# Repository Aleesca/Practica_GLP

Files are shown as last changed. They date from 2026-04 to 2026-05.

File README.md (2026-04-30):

# Proyecto de Instalacion de GLP

Base documental y de coordinacion para el calculo y diseno de una instalacion de almacenamiento y distribucion de GLP del grupo `G1-1`.

## Quick Start

1. Revisa el alcance en `Proyecto/Alcance.md`.
2. Revisa los datos de partida en `Proyecto/Datos.md`.
3. Usa `Proyecto/Planificacion/esquema_memoria.md` y `Proyecto/Especificaciones/metodologia.md` como contrato de trabajo.
4. Desarrolla las notas tecnicas en `Proyecto/Anotaciones/` y la salida final en `Proyecto/Especificaciones/`.
5. Consulta la documentacion tecnica de apoyo en `.agents/skills/doc_tecnica_glp/`.
6. Consolida editorialmente en `Practica_GLPs_LaTeX/` solo cuando el contenido Markdown ya este cerrado.

## Estructura operativa

- `00_Info_proporcionada/`: datos de partida, enunciado y modelo base del proyecto.
- `01_Planos/`: planos de trabajo y archivo CAD base.
- `Proyecto/Planificacion/`: gobierno documental, trazabilidad y planes de trabajo.
- `Proyecto/Especificaciones/`: salida tecnica primaria en Markdown modular.
- `Proyecto/Anotaciones/`: notas tecnicas, criterios y soporte intermedio.
- `.agents/skills/`: skills operativas canonicas del proyecto.
- `Proyecto/skills/`: espejo temporal de skills para apoyo documental.
- `Practica_GLPs_LaTeX/`: consolidacion editorial posterior; no es la fuente de verdad tecnica.
- `ZZ_Normativa/`: normativa de referencia y documentos reglamentarios.

## Decisiones de arquitectura

- El flujo activo se gobierna por `Proyecto/Alcance.md`, `Proyecto/Datos.md`, `Proyecto/Planificacion/esquema_memoria.md` y `Proyecto/Especificaciones/metodologia.md`.
- `Proyecto/Especificaciones/` es la salida primaria del sistema.
- `Practica_GLPs_LaTeX/` se mantiene como capa de consolidacion posterior.
- `.agents/skills/` es la ubicacion operativa de skills.
- `Proyecto/skills/` se conserva como espejo temporal y no debe gobernar el sistema activo.

## Documentacion clave

- `Proyecto/Alcance.md`
- `Proyecto/Datos.md`
- `Proyecto/Planificacion/esquema_memoria.md`
- `Proyecto/Especificaciones/metodologia.md`
- `Proyecto/Planificacion/matriz_fuentes.md`
- `Proyecto/Planificacion/mapa_citas.md`

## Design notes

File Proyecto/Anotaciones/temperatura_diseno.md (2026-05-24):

# Temperatura exterior de calculo

Esta nota fija el criterio para determinar la temperatura exterior de diseño del proyecto, basándose en referencias técnicas oficiales y el ajuste local.

## Referencia Técnica
Se adopta el criterio de la **Guía técnica: Condiciones climáticas exteriores de proyecto** (IDAE), utilizando el **percentil 99,6%** ajustado.

- **Fuente:** [IDAE - Guía técnica condiciones climáticas](https://www.idae.es/uploads/documentos/documentos_12_Guia_tecnica_condiciones_climaticas_exteriores_de_proyecto_e4e5b769.pdf)
- **Ubicación:** León (Virgen del Camino).
- **Temperatura de cálculo (99,6%):** **-5 ºC**.

## Uso en el proyecto
Esta temperatura es fundamental para la comprobación de la [vaporización natural](vaporizacion_natural.md) de los depósitos seleccionados en [seleccion_deposito.md](seleccion_deposito.md).

---
**Véase también:**
- [Vaporización natural](vaporizacion_natural.md)
- [Vaporización forzada](vaporizacion_forzada.md)
- [Selección del depósito](seleccion_deposito.md)
- [Potencia del armario de calefacción](potencia_armario_calefaccion.md)
- [Memoria: Hipótesis y datos de partida](../Especificaciones/datos-partida.md)
- [Memoria: Vaporización natural vs. vaporización forzada](../Especificaciones/vaporizacion.md)
- [Memoria: Conclusiones y limitaciones del proyecto](../Especificaciones/conclusiones-limitaciones.md)

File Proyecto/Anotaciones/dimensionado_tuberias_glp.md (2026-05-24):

# Dimensionado de tuberias GLP

El presente documento desarrolla el dimensionado de la red de distribucion de GLP en fase gas, incluyendo criterios de calculo, seleccion de materiales, formulacion hidraulica, optimizacion de diametros y resultados finales por tramo.

## Criterios tecnicos adoptados

El dimensionado de la red de distribucion de GLP se realiza para un regimen de media presion, con presion inicial relativa de `1.70 bar`. La perdida de carga admisible se limita al `5.0%` de dicha presion inicial, lo que fija una presion minima de servicio en el extremo mas desfavorable de `1.615 bar relativos`.

La red se calcula para propano en fase gas. Se adopta densidad corregida Renouard `dc = 1.16` y poder calorifico superior de `13.95 kWh/kg` para transformar la potencia termica instalada en caudal masico. El paso a caudal volumetrico se realiza con densidad de propano gas `1.882 kg/m3`.

La red se proyecta para GLP en fase gas y trazado exterior aereo. Se adopta tuberia metalica de cobre duro estirado sin soldadura conforme a EN 1057, con espesor minimo de 1 mm, por su compatibilidad con instalaciones receptoras de GLP y por permitir ejecucion vista protegida. El polietileno se descarta para estos tramos al tratarse de conduccion aerea expuesta; el acero al carbono se considera alternativa tecnica posible si se justifica proteccion frente a corrosion y autorizacion/criterio especifico aplicable a media presion.

### Criterio de velocidad: limite aereo y limite de proyecto

Para una canalizacion aerea de GLP en fase gas se toma como referencia general el limite maximo de `20 m/s`, asociado a redes generales de distribucion y acometidas aereas. No obstante, el presente proyecto no corresponde a una red general de distribucion de GLP canalizado para distintos abonados, sino a una instalacion receptora alimentada desde almacenamiento propio que suministra a consumidores finales de un unico usuario industrial. De acuerdo con la clasificacion tecnica de instalaciones receptoras, cuando existe un unico usuario la IRG se considera instalacion individual; para instalacion comun o individual el limite de velocidad aplicable es `10 m/s`. Por ello se adopta `10 m/s` como limite de proyecto y `8-10 m/s` como rango operativo preferente. El valor `20 m/s` queda documentado solo como limite maximo de referencia para conducciones aereas generales, pero no gobierna la seleccion de diametros de esta instalacion receptora industrial.

La fuente de calculo empleada establece tres limites de velocidad por tipo de conduccion: `30 m/s` para red general enterrada, `20 m/s` para red general y acometidas aereas, y `10 m/s` para instalacion comun en edificios e instalacion individual. La misma documentacion define que la red de distribucion no existe en GLP a granel y que, si la instalacion receptora suministra a un unico usuario, se considera instalacion individual. En consecuencia, cada tramo se comprueba frente a `v <= 10.0 m/s` como criterio aplicable de proyecto; el valor `v <= 20.0 m/s` se conserva solo como contraste de limite aereo general. La seleccion final prioriza el intervalo `8-10 m/s` cuando el catalogo y la presion disponible lo permiten.

Desde el punto de vista de optimizacion, el diametro seleccionado no se determina unicamente por velocidad. Para cada tramo se comprueba simultaneamente la condicion de aplicacion de Renouard `Q/D < 150`, la presion minima final, la velocidad practica y el catalogo comercial disponible. En tramos terminales de pequeno caudal puede aparecer velocidad baja cuando ya se ha alcanzado el diametro comercial minimo. En ramales de mayor longitud se evalua ademas el equilibrio entre aumentar ligeramente el tramo comun aguas arriba y reducir el diametro del ramal final, usando la masa lineal del tubo como estimador tecnico del coste.

## Material y catalogo de calculo

Material adoptado: **Cobre duro estirado sin soldadura EN 1057, espesor minimo 1 mm, instalacion aerea protegida**.

Se selecciona cobre duro estirado sin soldadura como material metalico apto para la red exterior en fase gas de GLP. Esta solución evita recurrir a PE en tramos aereos y simplifica la proteccion frente a corrosion respecto al acero al carbono. El PE se descarta por ser canalizacion aerea exterior. La alternativa de acero al carbono queda tecnicamente posible solo con proteccion pasiva y autorizacion o documentacion especifica. La seleccion queda supeditada a que el material mantenga presion maxima admisible suficiente frente a la presion de servicio y a las condiciones de montaje exterior.

El catalogo utilizado incorpora diametro interior, espesor, diametro exterior y masa lineal estimada a partir de la seccion metalica y densidad del cobre `8960 kg/m3`. Esta masa lineal se emplea solo como criterio comparativo interno para seleccionar alternativas equivalentes desde el punto de vista hidraulico.

Las dimensiones comerciales y masas lineales empleadas se han contrastado con tablas de tuberia de cobre conforme a EN 1057 para aplicaciones de agua/gas y con tablas tecnicas de instalaciones de GLP. Como referencias externas de material se consideran: [EN 1057:2006+A1:2010 - seamless copper tubes for water and gas](https://standards.iteh.ai/catalog/standards/cen/472e132f-b218-4e1e-9158-a3974034b500/en-1057-2006a1-2010), [Manual de instalaciones de GLP - Cepsa](https://15f8034cdff6595cbfa1-1dd67c28d3aade9d3442ee99310d18bd.ssl.cf3.rackcdn.com/04422d24271abec52042f58a558069bf/1_09_glp_cepsa.pdf), [COPTECH - tubos de cobre duro R290 EN 1057](https://www.copper.rs/hard.html) y [ALSIMET - tabla de tubo sanitario EN 1057](https://alsimet.es/en/copper/copper-tubes/sanitary-copper). Estas referencias se usan para justificar el tipo de tubo, la nomenclatura `diametro exterior x espesor`, el uso de cobre duro y la estimacion de masa lineal; el catalogo definitivo debera validarse con el proveedor antes de presupuesto.

| material | designacion | D_int_mm | espesor_mm | D_ext_mm | area_metal_mm2 | masa_lineal_kg_m |
| --- | --- | --- | --- | --- | --- | --- |
| cobre_duro_en1057 | 15x1 | 13.000 | 1.000 | 15.000 | 43.982 | 0.394 |
| cobre_duro_en1057 | 18x1.5 | 15.000 | 1.500 | 18.000 | 77.754 | 0.697 |
| cobre_duro_en1057 | 18x1 | 16.000 | 1.000 | 18.000 | 53.407 | 0.479 |
| cobre_duro_en1057 | 20x1.5 | 17.000 | 1.500 | 20.000 | 87.179 | 0.781 |
| cobre_duro_en1057 | 22x1 | 20.000 | 1.000 | 22.000 | 65.973 | 0.591 |
| cobre_duro_en1057 | 28x1 | 26.000 | 1.000 | 28.000 | 84.823 | 0.760 |
| cobre_duro_en1057 | 35x1.5 | 32.000 | 1.500 | 35.000 | 157.865 | 1.414 |
| cobre_duro_en1057 | 42x1.5 | 39.000 | 1.500 | 42.000 | 190.852 | 1.710 |
| cobre_duro_en1057 | 54x2 | 50.000 | 2.000 | 54.000 | 326.726 | 2.927 |
| cobre_duro_en1057 | 64x2 | 60.000 | 2.000 | 64.000 | 389.557 | 3.490 |
| cobre_duro_en1057 | 76.1x2 | 72.100 | 2.000 | 76.100 | 465.584 | 4.172 |
| cobre_duro_en1057 | 88.9x2 | 84.900 | 2.000 | 88.900 | 546.009 | 4.892 |
| cobre_duro_en1057 | 108x2.5 | 103.000 | 2.500 | 108.000 | 828.595 | 7.424 |

## Formulacion empleada

La potencia de cada consumidor se transforma a caudal masico y volumetrico mediante:

```text
Q_kg/h = P_kW / PCS_propano
Q_m3/h = Q_kg/h / rho_propano_gas
```

Para el consumidor `C6`, de `1000 kW`, resulta:

```text
Q_kg/h = 1000 / 13.95 = 71.68 kg/h
Q_m3/h = 71.68 / 1.882 = 38.09 m3/h
```

La longitud de calculo se obtiene sumando a la longitud geometrica la longitud equivalente de accesorios:

```text
Lc(D) = Lreal + sum(n_i * K_i * D_mm / 1000)
```

Para el tramo `E-C6`, con `Lreal = 14.46 m`, diametro interior `26 mm` y accesorios equivalentes `te_desviada + valvula_corte + reduccion`, se obtiene `Lc = 16.540 m`.

La perdida de carga en media presion se calcula con Renouard:

```text
PA_abs^2 - PB_abs^2 = 51.5 * dc * Lc * Q^1.82 / D^4.82
```

Para `E-C6`, con `PA_rel = 1.641 bar`, `Q = 38.090 m3/h`, `D = 26 mm` y `Lc = 16.540 m`, la presion final calculada es `PB_rel = 1.620 bar`, con perdida de carga `0.021 bar`.

La velocidad del gas se comprueba mediante:

```text
v = 378.04 * Q / (P_abs * D^2)
```

En el mismo tramo `E-C6`, el resultado es `v = 8.089 m/s`, dentro del rango operativo de `8-10 m/s`.

## Consumidores y caudales

| nodo | nombre | potencia_kw | q_kg_h | q_m3_h |
| --- | --- | --- | --- | --- |
| C1 | Horno secado 1 | 60 | 4.301 | 2.285 |
| C2 | Horno secado 2 | 60 | 4.301 | 2.285 |
| C3 | Caldera vapor | 500 | 35.842 | 19.045 |
| C4 | Caldera agua caliente | 300 | 21.505 | 11.427 |
| C5 | Horno fusion | 700 | 50.179 | 26.663 |
| C6 | Horno decapado | 1000 | 71.685 | 38.090 |

## Topologia y caudales por tramo

Los caudales aguas arriba se obtienen por suma de los consumidores descendentes, sin simultaneidad adicional. La fila inicial de derivaciones verticales de deposito se trata como cuatro subtramos equivalentes de `1,90 m` y se resume agrupada en la tabla posterior.

| designacion | tipo_tramo | nodo_ini | nodo_fin | longitud_m | q_m3_h | q_kg_h |
| --- | --- | --- | --- | --- | --- | --- |
| D1-D4 | derivacion_deposito | D1 | D4 | 1.900 | 24.949 | 46.953 |
| D2-D4 | derivacion_deposito | D2 | D4 | 1.900 | 24.949 | 46.953 |
| D3-D4 | derivacion_deposito | D3 | D4 | 1.900 | 24.949 | 46.953 |
| D4 vertical | derivacion_deposito | D4_dep | D4 | 1.900 | 24.949 | 46.953 |
| D4-A | red_principal | D4 | A | 15.120 | 99.795 | 187.814 |
| A-C1 | red_principal | A | C1 | 1.810 | 2.285 | 4.301 |
| A-B | red_principal | A | B | 4.970 | 97.509 | 183.513 |
| B-C2 | red_principal | B | C2 | 21.790 | 2.285 | 4.301 |
| B-C | red_principal | B | C | 17.320 | 95.224 | 179.211 |
| C-C3 | red_principal | C | C3 | 1.750 | 19.045 | 35.842 |
| C-D | red_principal | C | D | 10.770 | 76.179 | 143.369 |
| D-C4 | red_principal | D | C4 | 1.680 | 11.427 | 21.505 |
| D-E | red_principal | D | E | 13.060 | 64.752 | 121.864 |
| E-C5 | red_principal | E | C5 | 1.690 | 26.663 | 50.179 |
| E-C6 | red_principal | E | C6 | 14.460 | 38.090 | 71.685 |

## Accesorios considerados

El inventario de accesorios se introduce como longitud equivalente proporcional al diametro. Se consideran codos por cambios de direccion, tes en derivaciones, valvulas de corte por consumidor y por salida de deposito, y reducciones cuando el ramal deriva hacia un diametro inferior.

En el tramo `B-C2` se conserva la longitud real `21,79 m`, ya que corresponde a la suma de `0,53 m` a nivel de suelo, `8,00 m` de subida, `5,26 m` de tramo horizontal aereo y `8,00 m` de bajada. La revision no altera dicha longitud geometrica, pero si incorpora cuatro codos de 90 grados asociados a los cambios de direccion suelo-subida, subida-horizontal, horizontal-bajada y conexion final al consumidor. El desnivel no se corrige mediante termino hidrostatico porque el ramal sube y baja hasta una cota final equivalente y la comprobacion se realiza para GLP en fase gas.

| designacion | accesorio | cantidad | coef_leq_D | criterio |
| --- | --- | --- | --- | --- |
| D1-D4 | codo_90 | 1 | 30 | visible/hipotesis conservadora segun esquema_instalacion.pdf |
| D1-D4 | valvula_corte | 1 | 10 | visible/hipotesis conservadora segun esquema_instalacion.pdf |
| D2-D4 | codo_90 | 1 | 30 | visible/hipotesis conservadora segun esquema_instalacion.pdf |
| D2-D4 | valvula_corte | 1 | 10 | visible/hipotesis conservadora segun esquema_instalacion.pdf |
| D3-D4 | codo_90 | 1 | 30 | visible/hipotesis conservadora segun esquema_instalacion.pdf |
| D3-D4 | valvula_corte | 1 | 10 | visible/hipotesis conservadora segun esquema_instalacion.pdf |
| D4 vertical | codo_90 | 1 | 30 | visible/hipotesis conservadora segun esquema_instalacion.pdf |
| D4 vertical | valvula_corte | 1 | 10 | visible/hipotesis conservadora segun esquema_instalacion.pdf |
| D4-A | codo_90 | 1 | 30 | visible/hipotesis conservadora segun esquema_instalacion.pdf |
| D4-A | valvula_corte | 1 | 10 | visible/hipotesis conservadora segun esquema_instalacion.pdf |
| D4-A | te_linea | 1 | 20 | visible/hipotesis conservadora segun esquema_instalacion.pdf |
| A-C1 | te_desviada | 1 | 60 | visible/hipotesis conservadora segun esquema_instalacion.pdf |
| A-C1 | valvula_corte | 1 | 10 | visible/hipotesis conservadora segun esquema_instalacion.pdf |
| A-C1 | reduccion | 1 | 10 | visible/hipotesis conservadora segun esquema_instalacion.pdf |
| A-B | codo_90 | 1 | 30 | visible/hipotesis conservadora segun esquema_instalacion.pdf |
| A-B | te_linea | 1 | 20 | visible/hipotesis conservadora segun esquema_instalacion.pdf |
| B-C2 | te_desviada | 1 | 60 | visible/hipotesis conservadora segun esquema_instalacion.pdf |
| B-C2 | valvula_corte | 1 | 10 | visible/hipotesis conservadora segun esquema_instalacion.pdf |
| B-C2 | reduccion | 1 | 10 | visible/hipotesis conservadora segun esquema_instalacion.pdf |
| B-C2 | codo_90 | 4 | 30 | visible/hipotesis conservadora segun esquema_instalacion.pdf |
| B-C | codo_90 | 1 | 30 | visible/hipotesis conservadora segun esquema_instalacion.pdf |
| B-C | te_linea | 1 | 20 | visible/hipotesis conservadora segun esquema_instalacion.pdf |
| C-C3 | te_desviada | 1 | 60 | visible/hipotesis conservadora segun esquema_instalacion.pdf |
| C-C3 | valvula_corte | 1 | 10 | visible/hipotesis conservadora segun esquema_instalacion.pdf |
| C-C3 | reduccion | 1 | 10 | visible/hipotesis conservadora segun esquema_instalacion.pdf |
| C-D | codo_90 | 1 | 30 | visible/hipotesis conservadora segun esquema_instalacion.pdf |
| C-D | te_linea | 1 | 20 | visible/hipotesis conservadora segun esquema_instalacion.pdf |
| D-C4 | te_desviada | 1 | 60 | visible/hipotesis conservadora segun esquema_instalacion.pdf |
| D-C4 | valvula_corte | 1 | 10 | visible/hipotesis conservadora segun esquema_instalacion.pdf |
| D-C4 | reduccion | 1 | 10 | visible/hipotesis conservadora segun esquema_instalacion.pdf |
| D-E | codo_90 | 1 | 30 | visible/hipotesis conservadora segun esquema_instalacion.pdf |
| D-E | te_linea | 1 | 20 | visible/hipotesis conservadora segun esquema_instalacion.pdf |
| E-C5 | te_desviada | 1 | 60 | visible/hipotesis conservadora segun esquema_instalacion.pdf |
| E-C5 | valvula_corte | 1 | 10 | visible/hipotesis conservadora segun esquema_instalacion.pdf |
| E-C5 | reduccion | 1 | 10 | visible/hipotesis conservadora segun esquema_instalacion.pdf |
| E-C6 | te_desviada | 1 | 60 | visible/hipotesis conservadora segun esquema_instalacion.pdf |
| E-C6 | valvula_corte | 1 | 10 | visible/hipotesis conservadora segun esquema_instalacion.pdf |
| E-C6 | reduccion | 1 | 10 | visible/hipotesis conservadora segun esquema_instalacion.pdf |

### Sensibilidad del tramo B-C2

| subtramo | descripcion | longitud_m | tipo |
| --- | --- | --- | --- |
| B-C2.1 | tramo inicial a nivel de suelo | 0.530 | horizontal_suelo |
| B-C2.2 | subida vertical hasta tramo aereo | 8.000 | vertical_subida |
| B-C2.3 | tramo horizontal aereo | 5.260 | horizontal_aereo |
| B-C2.4 | bajada vertical hasta consumidor C2 | 8.000 | vertical_bajada |

La comparacion siguiente muestra el efecto de incorporar los codos del trazado vertical-aereo. El diametro se mantiene en `15x1`, por ser el minimo del catalogo adoptado y porque la presion final sigue por encima del minimo admisible.

| escenario | designacion_tubo | D_int_mm | Lc_m | P_ini_rel_bar | P_fin_rel_bar | delta_p_bar | velocidad_ms | incremento_Lc_m | incremento_delta_p_bar |
| --- | --- | --- | --- | --- | --- | --- | --- | --- | --- |
| anterior: sin codos vertical-aereo adicionales | 15x1 | 13.000 | 22.830 | 1.675 | 1.670 | 0.005 | 1.905 | 0.000 | 0.000 |
| revisado: con 4 codos 90 por subida/bajada | 15x1 | 13.000 | 24.390 | 1.675 | 1.670 | 0.005 | 1.905 | 1.560 | 0.000 |

Como condicion constructiva, el tramo aereo debe resolverse con soportes que no carguen sobre uniones, separacion respecto a paramentos, proteccion anticorrosiva, identificacion de fase gas y previsiones de dilatacion si la longitud expuesta queda sometida a variaciones termicas relevantes.

## Derivaciones verticales de deposito

| designacion | unidades | longitud_m_por_unidad | q_m3_h_por_unidad | designacion_tubo | D_int_mm | Lc_m_por_unidad | P_fin_rel_bar_min | velocidad_ms_max | estado |
| --- | --- | --- | --- | --- | --- | --- | --- | --- | --- |
| D1/D2/D3/D4 verticales | 4 | 1.900 | 24.949 | 20x1.5 | 17.000 | 2.580 | 1.688 | 12.080 | Conforme |

### Verificacion y Justificacion de Cumplimiento de la Normativa UNE 60250

De acuerdo con la norma **UNE 60250** ("Instalaciones de almacenamiento de GLP en depositos fijos para su consumo en instalaciones receptoras"), la zona de almacenamiento (los depositos y sus derivaciones inmediatas hasta el colector comun) esta sujeta a requisitos especificos de resistencia mecanica y seguridad pasiva frente a incendios:

1. **Requisitos de Tuberia de Cobre en la Zona del Deposito (UNE 60250):**
   * **Espesor minimo:** Las conducciones de cobre situadas en la zona de almacenamiento deben tener un espesor de pared de al menos **1.5 mm** (`espesor_mm >= 1.5`).
   * **Diametro exterior maximo:** El diametro nominal maximo para estas derivaciones es de **DN 20** (diametro exterior de **20 mm**).
   * **Inconformidad del diseño original:** El diseño inicial contemplaba tuberias de cobre de `22x1` para las derivaciones verticales de los depositos (`D1-D4`, `D2-D4`, `D3-D4`, `D4 vertical`). Este diseño resultaba doblemente no conforme:
     * El espesor de pared de `1.0 mm` no alcanzaba el minimo de `1.5 mm`.
     * El diametro exterior de `22.0 mm` superaba el limite reglamentario de `20.0 mm`.
   * **Seleccion del diametro conforme:** Tras filtrar el catalogo comercial por los requisitos de la UNE 60250, se selecciono el diametro **20x1.5** (diametro exterior de 20 mm, espesor de 1.5 mm, diametro interior de 17 mm).

2. **Criterios de Velocidad y Perdida de Carga:**
   * **Velocidad del fluido:** Con el diametro adoptado de `20x1.5`, la velocidad maxima alcanzada en las derivaciones verticales es de **12.08 m/s** para el caudal punta por deposito. Aunque este valor supera el limite practico de `10.0 m/s` establecido para la red receptora interior (UNE 60670), es plenamente conforme bajo la UNE 60250, que permite un limite absoluto de velocidad de **20 m/s** en conducciones aereas de almacenamiento y distribucion exterior.
   * **Perdida de carga:** La caida de presion en cada ramal es de solo **0.012 bar**, manteniendo la presion final en el nodo colector en **1.688 bar relativos**, asegurando que no se penalice el funcionamiento hidraulico del sistema.

3. **Requisitos de las Uniones y Accesorios (UNE-EN 1254-1 / UNE 60250):**
   * **Soldadura capilar fuerte:** Para garantizar la estanqueidad y evitar fallos por fatiga termica o exposicion directa al fuego, las uniones de las tuberias en el area de almacenamiento deben ser mediante **soldadura fuerte con metal de aportación que tenga un punto de fusion superior a 450 °C**. Queda estrictamente prohibido el uso de soldadura blanda en esta zona.
   * **Impacto en accesorios de reduccion:** La sustitucion del ramal a `20x1.5` en lugar de `22x1` modifica las uniones al colector comun de `42x1.5`. Se requiere la instalacion de **5 reducciones de cobre de 42 mm a 20 mm** (en las conexiones de los 4 depositos y en el tramo de derivacion `C-C3` que tambien optimizo a `20x1.5` por balance de velocidad), sustituyendo las reducciones de `42x22` originalmente previstas.

## Optimizacion hidraulica y economica del subarbol E

El tramo `E-C6` es un ramal largo con caudal relevante. El dimensionado secuencial inicial mantenia `D-E` en `35x1.5` y obligaba a seleccionar `E-C6` en `35x1.5` para cumplir presion, lo que dejaba una velocidad baja en el ramal final. Para evitar esta solucion local, se evalua de forma combinada el conjunto `D-E`, `E-C5` y `E-C6`.

La seleccion se realiza sobre combinaciones comerciales que cumplen `Q/D`, presion minima y `v <= 10.0 m/s`, ordenadas por masa equivalente total de cobre. La alternativa adoptada incrementa `D-E` a `42x1.5`, reduciendo su perdida de carga a `0.007 bar` y elevando la presion disponible en el nodo `E` hasta `1.641 bar`. Con esa presion disponible, `E-C6` puede reducirse a `28x1` y queda con velocidad `8.089 m/s`, dentro del rango objetivo.

| D-E_tubo | E-C5_tubo | E-C6_tubo | D-E_velocidad_ms | E-C5_velocidad_ms | E-C6_velocidad_ms | D-E_P_fin_rel_bar | E-C5_P_fin_rel_bar | E-C6_P_fin_rel_bar | masa_total_kg |
| --- | --- | --- | --- | --- | --- | --- | --- | --- | --- |
| 42x1.5 | 22x1 | 28x1 | 6.062 | 9.520 | 8.089 | 1.641 | 1.634 | 1.620 | 34.322 |
| 42x1.5 | 28x1 | 28x1 | 6.062 | 5.622 | 8.089 | 1.641 | 1.639 | 1.620 | 34.607 |
| 42x1.5 | 35x1.5 | 28x1 | 6.062 | 3.709 | 8.089 | 1.641 | 1.640 | 1.620 | 35.713 |
| 42x1.5 | 42x1.5 | 28x1 | 6.062 | 2.497 | 8.089 | 1.641 | 1.641 | 1.620 | 36.213 |
| 42x1.5 | 54x2 | 28x1 | 6.062 | 1.519 | 8.089 | 1.641 | 1.641 | 1.620 | 38.270 |

La velocidad de `D-E` queda en `6.062 m/s`, por debajo del rango preferente, pero se considera justificada porque el tramo comun conserva margen de presion y permite reducir material en el ramal largo `E-C6`. El tramo `E-C5` mantiene `22x1` con velocidad `9.520 m/s`.

## Justificacion de velocidades bajas

Determinados tramos presentan velocidades inferiores al rango preferente `8-10 m/s`. Estos casos no se clasifican automaticamente como sobredimensionado, ya que el criterio principal es garantizar simultaneamente presion minima, condicion `Q/D < 150`, diametro comercial disponible y velocidad maxima admisible. La velocidad baja se acepta solo cuando existe una causa tecnica identificable.

- `A-C1` y `B-C2`: ambos alimentan consumidores de `60 kW`, con caudal `2.285 m3/h`. El diametro seleccionado es `15x1`, con diametro interior `13 mm`, que es el minimo del catalogo adoptado. En `B-C2`, la revision del trazado vertical-aereo aumenta la longitud de calculo por los cuatro codos adicionales, pero el diametro no cambia y la presion final permanece conforme. La velocidad resultante queda en torno a `1.9 m/s`; reducir el diametro para aproximarse a `8-10 m/s` exigiria introducir un tubo no contemplado en el catalogo de calculo y con menor robustez mecanica. Por tanto, la baja velocidad se justifica por caudal reducido, diametro comercial minimo y margen de presion suficiente aun incorporando los cambios de direccion.

- `C-C3`: alimenta el consumidor de `500 kW`, con caudal `19.045 m3/h`. El tubo `22x1` proporciona `6.752 m/s`, por debajo del rango preferente pero cumpliendo presion y `Q/D`. El diametro inmediatamente inferior elevaria la velocidad, pero penalizaria la perdida de carga y reduciria el margen de presion disponible en un ramal conectado a la red principal. Se mantiene `22x1` como equilibrio entre margen hidraulico y dimension comercial.

- `C-D`: transporta el caudal remanente hacia los consumidores `C4`, `C5` y `C6`. La seleccion `42x1.5` da `7.113 m/s`, ligeramente inferior al objetivo, pero mantiene margen de presion para el subarbol final y evita trasladar una perdida excesiva a los ramales aguas abajo. La velocidad baja se considera admisible por equilibrio hidraulico de conjunto.

- `D-E`: tras la optimizacion combinada del subarbol `E`, se adopta `42x1.5`, con `6.062 m/s`. Esta reduccion de velocidad en el tramo comun permite elevar la presion en el nodo `E` y reducir `E-C6` a `28x1`, donde la velocidad pasa a `8.089 m/s`. El criterio no minimiza la velocidad de cada tramo de forma aislada, sino la solucion conjunta de presion, perdida de carga y masa equivalente de tubo.

## Resultados de dimensionado

| designacion | tipo_tramo | longitud_m | q_m3_h | designacion_tubo | D_int_mm | Lc_m | Q_D | P_ini_rel_bar | P_fin_rel_bar | delta_p_bar | velocidad_ms | criterio_seleccion | estado |
| --- | --- | --- | --- | --- | --- | --- | --- | --- | --- | --- | --- | --- | --- |
| D1-D4 | derivacion_deposito | 1.900 | 24.949 | 20x1.5 | 17.000 | 2.580 | 1.468 | 1.700 | 1.688 | 0.012 | 12.080 | no hay candidato <=10 m/s; se mantiene bajo limite aereo absoluto de 20 m/s | Conforme - velocidad alta admisible por limite aereo general |
| D2-D4 | derivacion_deposito | 1.900 | 24.949 | 20x1.5 | 17.000 | 2.580 | 1.468 | 1.700 | 1.688 | 0.012 | 12.080 | no hay candidato <=10 m/s; se mantiene bajo limite aereo absoluto de 20 m/s | Conforme - velocidad alta admisible por limite aereo general |
| D3-D4 | derivacion_deposito | 1.900 | 24.949 | 20x1.5 | 17.000 | 2.580 | 1.468 | 1.700 | 1.688 | 0.012 | 12.080 | no hay candidato <=10 m/s; se mantiene bajo limite aereo absoluto de 20 m/s | Conforme - velocidad alta admisible por limite aereo general |
| D4 vertical | derivacion_deposito | 1.900 | 24.949 | 20x1.5 | 17.000 | 2.580 | 1.468 | 1.700 | 1.688 | 0.012 | 12.080 | no hay candidato <=10 m/s; se mantiene bajo limite aereo absoluto de 20 m/s | Conforme - velocidad alta admisible por limite aereo general |
| D4-A | red_principal | 15.120 | 99.795 | 42x1.5 | 39.000 | 17.460 | 2.559 | 1.700 | 1.682 | 0.018 | 9.203 | diametro con velocidad dentro de 8-10 m/s mas cercana a 9.5 m/s | Conforme - velocidad objetivo |
| A-C1 | red_principal | 1.810 | 2.285 | 15x1 | 13.000 | 2.850 | 0.176 | 1.682 | 1.681 | 0.001 | 1.897 | diametro mas cercano al rango objetivo sin superar el limite practico de 10 m/s | Conforme - velocidad baja justificada |
| A-B | red_principal | 4.970 | 97.509 | 42x1.5 | 39.000 | 6.920 | 2.500 | 1.682 | 1.675 | 0.007 | 9.015 | diametro con velocidad dentro de 8-10 m/s mas cercana a 9.5 m/s | Conforme - velocidad objetivo |
| B-C2 | red_principal | 21.790 | 2.285 | 15x1 | 13.000 | 24.390 | 0.176 | 1.675 | 1.670 | 0.005 | 1.905 | diametro mas cercano al rango objetivo sin superar el limite practico de 10 m/s | Conforme - velocidad baja justificada |
| B-C | red_principal | 17.320 | 95.224 | 42x1.5 | 39.000 | 19.270 | 2.442 | 1.675 | 1.657 | 0.018 | 8.864 | diametro con velocidad dentro de 8-10 m/s mas cercana a 9.5 m/s | Conforme - velocidad objetivo |
| C-C3 | red_principal | 1.750 | 19.045 | 20x1.5 | 17.000 | 3.110 | 1.120 | 1.657 | 1.648 | 0.009 | 9.361 | diametro con velocidad dentro de 8-10 m/s mas cercana a 9.5 m/s | Conforme - velocidad objetivo |
| C-D | red_principal | 10.770 | 76.179 | 42x1.5 | 39.000 | 12.720 | 1.953 | 1.657 | 1.649 | 0.008 | 7.113 | diametro mas cercano al rango objetivo sin superar el limite practico de 10 m/s | Conforme - velocidad baja justificada |
| D-C4 | red_principal | 1.680 | 11.427 | 15x1 | 13.000 | 2.720 | 0.879 | 1.649 | 1.638 | 0.011 | 9.642 | diametro con velocidad dentro de 8-10 m/s mas cercana a 9.5 m/s | Conforme - velocidad objetivo |
| D-E | red_principal | 13.060 | 64.752 | 42x1.5 | 39.000 | 15.010 | 1.660 | 1.649 | 1.641 | 0.007 | 6.062 | optimizacion economica del subarbol E: aumenta D-E para reducir masa total en E-C6 | Conforme - velocidad baja justificada |
| E-C5 | red_principal | 1.690 | 26.663 | 22x1 | 20.000 | 3.290 | 1.333 | 1.641 | 1.634 | 0.008 | 9.520 | seleccionado por optimizacion economica del subarbol E con presion aguas arriba recalculada | Conforme - velocidad objetivo |
| E-C6 | red_principal | 14.460 | 38.090 | 28x1 | 26.000 | 16.540 | 1.465 | 1.641 | 1.620 | 0.021 | 8.089 | seleccionado por optimizacion economica del subarbol E con presion aguas arriba recalculada | Conforme - velocidad objetivo |

## No conformidades

No se detectan no conformidades.

## Control manual de trazabilidad

Como control independiente se recalcula el tramo `D4-A`:

```text
Lc = 17.460 m
Q/D = 2.559
v = 9.203 m/s
```

El resultado confirma la coherencia entre longitud de calculo, caudal, diametro y velocidad final del tramo principal de alimentacion.

## Conclusion tecnica

Con las hipotesis adoptadas, la red queda dimensionada para un caudal punta simultaneo de `187.81 kg/h`, equivalente a `99.79 m3/h`. Todos los tramos cumplen la condicion de aplicacion `Q/D < 150`, la presion minima relativa de `1.615 bar` y el limite practico de velocidad adoptado. Las velocidades bajas que permanecen en ramales concretos responden al diametro comercial minimo o a una decision de equilibrio hidraulico-economico, y quedan justificadas de forma expresa en la tabla de resultados.

---
**Véase también:**
- [Memoria: Hipótesis y datos de partida](../Especificaciones/datos-partida.md)
- [Caudales de consumidores](caudales_consumidores.md)
- [Trazado de red](trazado_red.md)
- [Valvulería y accesorios](valvuleria_accesorios.md)
- [Criterios normativos](criterios_normativos.md)
- [Recopilación de accesorios y costes](recopilacion_accesorios_costes_glp.md)
- [Pliego de condiciones de equipos](pliego_condiciones_equipos_glp.md)
- [Memoria: Red de distribución y regulación](../Especificaciones/red-distribucion.md)
- [Especificación: Metodología de longitud y cálculo hidráulico](../Especificaciones/metodologia-longitud-calculo.md)
- [Especificación: Capítulo de Cálculos justificados](../Especificaciones/calculos-justificados.md)
- [Especificación: Presupuesto y mediciones](../Especificaciones/presupuesto.md)

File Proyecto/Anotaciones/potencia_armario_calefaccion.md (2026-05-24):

# Potencia del armario de calefaccion

Esta nota documenta el criterio de calculo de la potencia termica minima del armario de calefaccion asociado al sistema de [vaporizacion forzada](vaporizacion_forzada.md).

## 1. Necesidad tecnica del armario

La [vaporizacion natural](vaporizacion_natural.md) de la bateria de depositos no cubre la demanda punta de la instalacion en la condicion critica de diseno. La comprobacion se realiza con:

- Temperatura exterior de calculo: **-5 ºC**, definida en [temperatura_diseno.md](temperatura_diseno.md).
- Nivel minimo operativo: **20%** de llenado.
- Presion de comprobacion: **2 bar**.

En estas condiciones, la demanda punta obtenida a partir de los [caudales de consumidores](caudales_consumidores.md) es **187,81 kg/h**, mientras que la vaporizacion natural total de la bateria seleccionada es **131,30 kg/h**. Por tanto, aparece un deficit de:

$$
Q_{def} = 187,81 - 131,30 = 56,51\ \text{kg/h}
$$

Este deficit hace necesario un aporte termico externo. El armario de calefaccion no se incorpora como mejora opcional, sino como equipo funcional imprescindible para alimentar el circuito cerrado de agua caliente que transfiere calor al serpentín interno del vaporizador.

## 2. Criterio de dimensionado

El sistema adoptado en [seleccion_deposito.md](seleccion_deposito.md) es un deposito **LP46A-22** como modelo especial con vaporizador interno **VIA 150**. El criterio de dimensionado del armario se fija por la potencia minima de caldera requerida por el vaporizador seleccionado, no solo por el deficit instantaneo de vaporizacion natural.

Segun la tabla tecnica utilizada en `calculos/calculos.ipynb`, el **VIA 150** tiene:

- Capacidad de vaporizacion forzada: **150 kg/h**.
- Potencia minima de caldera: **17,5 kW**.

La consulta documental al notebook `GLP` confirma el mismo valor para el **VIA 150** y permite identificar que el armario **VPC30C** incorpora una caldera de **45 kW**.

La capacidad total garantizada con el sistema mixto queda:

$$
Q_{total} = Q_{natural} + Q_{forzada} = 131,30 + 150 = 281,30\ \text{kg/h}
$$

El margen frente a la demanda punta es:

$$
Q_{margen} = 281,30 - 187,81 = 93,49\ \text{kg/h}
$$

## 3. Resultado

La potencia termica minima exigida para el generador del armario de calefaccion asociado al **VIA 150** es:

$$
P_{armario,min} = 17,5\ \text{kW}
$$

El armario seleccionado, identificado en la documentacion del proyecto como **VPC30C**, incorpora una caldera de **45 kW**. La comprobacion de suficiencia queda:

$$
45,0\ \text{kW} \ge 17,5\ \text{kW}
$$

Por tanto, el margen de potencia termica disponible en el armario es:

$$
P_{margen} = 45,0 - 17,5 = 27,5\ \text{kW}
$$

## 4. Conclusion

La instalacion del armario de calefaccion es necesaria porque la vaporizacion natural disponible en las condiciones criticas de diseno no garantiza el caudal requerido por la instalacion. Con el vaporizador interno **VIA 150** y una potencia minima de caldera de **17,5 kW**, el sistema mixto alcanza **281,30 kg/h**, suficiente para cubrir la demanda punta de **187,81 kg/h**. El armario **VPC30C**, con **45 kW**, cubre la potencia minima exigida.

---
**Véase también:**
- [Caudales de consumidores](caudales_consumidores.md)
- [Vaporización natural](vaporizacion_natural.md)
- [Vaporización forzada](vaporizacion_forzada.md)
- [Selección del depósito](seleccion_deposito.md)
- [Temperatura exterior de cálculo](temperatura_diseno.md)
- [Pliego de condiciones de equipos](pliego_condiciones_equipos_glp.md)
- [Memoria: Vaporización natural vs. vaporización forzada](../Especificaciones/vaporizacion.md)
- [Memoria: Características de los equipos auxiliares del almacenamiento](../Especificaciones/equipos-auxiliares.md)
- [Memoria: Instalaciones auxiliares y de seguridad de la estación](../Especificaciones/instalaciones-auxiliares.md)

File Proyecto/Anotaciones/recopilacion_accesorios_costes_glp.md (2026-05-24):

# Recopilación y Coste de Accesorios por Tramo GLP (Refinado Final - Rev A)

## Introducción y Alcance
Este documento presenta la estimación técnico-económica definitiva para la instalación de GLP del Grupo G1-1. Se han consolidado los precios mediante investigación profunda, reflejando la configuración final de la batería de depósitos (125,1 m³) necesaria para cumplir con las distancias de seguridad en la parcela. Se utiliza a **Salvador Escoda** como proveedor consolidado para tubería de cobre.

## Fuentes de Consulta y Enlaces de Compra
- **Tubería y Valvulería de Corte**: [Salvador Escoda - Tarifa PVP Cobre/Gas](https://wrs01.salvadorescoda.com/Tarifas_web/actualizadas/Precios_Escoda_PVP_Cobre.pdf) / [Giacomini R731GA](https://es.giacomini.com/product/R731GA)
- **Reguladores**: [Clesse APS2000 (Catálogo Internacional)](https://clesse.eu/wp-content/uploads/2024/05/International_Catalogue.pdf)
- **Seguridad (Válvulas Alivio/Corte Depósito)**: [RegO Europe - RS 3145 / A 7508](https://www.rego-europe.de/)
- **Depósitos y Vaporización**: [Lapesa - Catálogo GLP 2024](https://www.lapesa.es/sites/default/files/nuevo_cat_glp-es-0121-10.pdf)

## Criterios Normativos Aplicados
| Familia | Norma | Requisito Clave | Estado |
| :--- | :--- | :--- | :--- |
| **Tubería** | UNE-EN 1057 | Cobre duro, espesor mín. 1 mm (aéreo) / 1,5 mm (enterrado). | Verificado |
| **Válvulas de Corte** | UNE-EN 331 | PN 16/25/40, -20ºC, mando amarillo para gas. | Verificado |
| **Válvulas Alivio** | UNE-EN 14129 | Taradas a 20 bar, precintadas y certificadas de origen. | Verificado |
| **Depósitos** | UNE 60250 | Distancias de seguridad críticas; fragmentación de volumen. | Cumplido |

## Partidas de Materiales (Proveedor Único: Salvador Escoda)
| Tramo | Diámetro | Componente | Cantidad | Precio Unit. (€/m o ud) | Total (€) |
| :--- | :--- | :--- | :--- | :--- | :--- |
| D1/2/3/4 | 20x1.5 mm | Tubo Cobre Barra | 7,60 m | 16,40 €/m | 124,64 € |
| D4-A / A-B | 42x1.5 mm | Tubo Cobre Barra | 20,09 m | 42,50 €/m | 853,83 € |
| B-C / C-D | 42x1.5 mm | Tubo Cobre Barra | 28,09 m | 42,50 €/m | 1.193,83 € |
| D-E | 42x1.5 mm | Tubo Cobre Barra | 13,06 m | 42,50 €/m | 555,05 € |
| E-C6 | 28x1 mm | Tubo Cobre Barra | 14,46 m | 21,14 €/m | 305,68 € |
| E-C5 / C-C3 | 22x1 mm | Tubo Cobre Barra | 3,44 m | 15,95 €/m | 54,87 € |
| Ramales 15 | 15x1 mm | Tubo Cobre Barra | 25,28 m | 10,73 €/m | 271,25 € |
| **Válvulas** | 15-28 mm | Giacomini R731GA | 6 ud | ~18,50 € (media) | 111,00 € |
| **Accesorios** | Varios | Codos/Tes Cobre | Estim. | 25% s/tubo | 842,29 € |

## Equipos Generales de la Instalación (Configuración LP46 + 3xLP26)
| Equipo | Referencia / Capacidad | Cantidad | Proveedor | Precio Unit. | Total (€) |
| :--- | :--- | :--- | :--- | :--- | :--- |
| **Depósito Principal**| LP46A-22 (46,2 m³) | 1 | Lapesa | 42.000,00 € | 42.000,00 € |
| **Serpentín Int.** | VIA 150 (Instalado) | 1 | Lapesa | Incluido* | - |
| **Depósito Apoyo** | LP26A-22 (26,3 m³) | 3 | Lapesa | 24.000,00 € | 72.000,00 € |
| **Armario Calef.** | Lapesa VPC30C | 1 | Lapesa | 12.500,00 € | 12.500,00 € |
| **Válvula Alivio** | RegO RS 3145 (20 bar) | 4 | RegO Europe | 230,00 € | 920,00 € |
| **Válvula Corte** | RegO A 7508 AP (1" Áng) | 4 | RegO Europe | 180,00 € | 720,00 € |
| **Regulador 1ª** | Clesse APS2000 (150kg/h)| 4 | Clesse | 340,00 € | 1.360,00 € |

*\*Nota: El precio del LP46A incluye el recargo por "Modelo Especial" con serpentín interno VIA 150 solicitado a medida.*

## Costes de Proyecto y Servicios (Presupuesto de Ingeniería)
| Concepto | Detalle | Importe (€) | Fuente/Hipótesis |
| :--- | :--- | :--- | :--- |
| **Mano de Obra** | Instalación, soldadura y montaje | 18.000,00 € | Estimado (15% equipos) |
| **Ingeniería** | Proyecto técnico y legalización | 4.500,00 € | Complejidad batería mixta|
| **Transporte** | Medios especiales y grúa | 3.500,00 € | 4 depósitos gran formato |
| **Pruebas** | Estanqueidad y OCA | 1.200,00 € | Tasas y medios técnicos |
| **Soportación** | Bancadas y fijaciones tubería | 2.400,00 € | Obra civil apoyo |
| **Contingencias** | 5% sobre total proyecto | 8.000,00 € | Imprevistos de obra |

## Resumen Económico Consolidado
| Categoría | Concepto | Importe (€) | Estado |
| :--- | :--- | :--- | :--- |
| **Materiales** | Tubería Cobre, Valvulería, Accesorios | 4.312,44 € | Verificado (Escoda) |
| **Equipos** | Depósitos (125m³), Vap., Armario | 129.500,00 €| Refinado (Deep Res.)|
| **Servicios** | Ingeniería, MO, Legalización, Pruebas | 37.600,00 € | Estimado Proyecto |
| **TOTAL INSTALACIÓN** | (Sin IVA) | **171.412,44 €** | |

## Fuentes de Consulta Detalladas y Enlaces de Precios
A continuación se detallan todos los enlaces y catálogos consultados para la elaboración de este presupuesto consolidado:

1.  **Tubería de Cobre (EN 1057):**
    *   [Salvador Escoda - Tarifa PVP Tubería Cobre](https://wrs01.salvadorescoda.com/Tarifas_web/actualizadas/Precios_Escoda_PVP_Cobre.pdf) (Referencia Principal)
    *   [Tecnihogar - Metro lineal tubo cobre 15x1](https://tecnihogar.es/fontaneria/tuberias/tuberias-cobre/metro-lineal-tubo-cobre-rigido-15-x-1-mm)
    *   [Grosshandel Hahn (DE) - Copper Rohr DIN EN 1057](https://www.grosshandel-hahn.de/shop/Installation/Rohrsysteme/Kupferrohe/RALKupferrohr_blank_DIN_EN_1057__halbhart_15_x_10_mm_in_5m_Stange_Stueckpreis__pa48697.htm)
    *   [Smith Brothers Stores - 22mm Copper Tube](https://sbsonline.net/22mm-copper-tube-3mtrs)
2.  **Valvulería de Corte y Gas:**
    *   [Giacomini R731GA - Válvula de esfera uso gas](https://es.giacomini.com/product/R731GA)
    *   [Giacomini R700 - Accesorio de vaciado](https://es.giacomini.com/producto/R700)
    *   [Salvador Escoda - Accesorios y Valvulería Gas](https://wrs01.salvadorescoda.com/Tarifas_web/Accesorios_Tarifa_PVP_SalvadorEscoda.pdf)
3.  **Regulación y Seguridad:**
    *   [Clesse APS2000 - Catálogo Internacional de Reguladores](https://clesse.eu/wp-content/uploads/2024/05/International_Catalogue.pdf)
    *   [RegO Europe - Válvula de Alivio RS 3145](https://www.rego-europe.de/literature/operating-instructions/)
    *   [RegO Europe - Válvula de Ángulo A 7508 AP](https://www.rego-europe.de/)
    *   [GasProducts (UK) - Copper Solder Fittings](https://www.gasproducts.co.uk/copper-solder-ring-straight-coupling-28mm.html)
4.  **Depósitos y Vaporización:**
    *   [Lapesa - Catálogo General GLP y Sistemas de Vaporización](https://www.lapesa.es/sites/default/files/nuevo_cat_glp-es-0121-10.pdf) (Referencia para LP46A y LP26A)
    *   [Matmax - Tarifas y PVP Lapesa (Consulta General)](https://www.matmax.es/marcas/lapesa)
5.  **Presupuestos Reales de Ingeniería:**
    *   [Contratación del Estado - Presupuesto Instalación GLP (Cantur)](https://contrataciondelestado.es/wps/wcm/connect/PLACE_es/Site/area/docAccCmpnt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)

## Referencias Cruzadas
- [Selección del depósito](seleccion_deposito.md)
- [Pliego de condiciones de equipos](pliego_condiciones_equipos_glp.md)
- [Valvulería y accesorios](valvuleria_accesorios.md)
- [Dimensionado de tuberías GLP](dimensionado_tuberias_glp.md)
- [Vaporización forzada](vaporizacion_forzada.md)
- [Reporte de accesorios](reporte_accesorios.md)
- [Especificación: Presupuesto y mediciones](../Especificaciones/presupuesto.md)
- [Memoria: Características de los equipos auxiliares del almacenamiento](../Especificaciones/equipos-auxiliares.md)
- [Memoria: Instalaciones auxiliares y de seguridad de la estación](../Especificaciones/instalaciones-auxiliares.md)
- [Memoria: Red de distribución y regulación](../Especificaciones/red-distribucion.md)

## Limitaciones y Notas Finales
- **Volatilidad del Cobre**: Los precios del cobre están sujetos a cotización diaria (LME); se recomienda revisión antes de compra.
- **Exclusividad**: Se ha cumplido el requisito de usar un proveedor único para tubería y fuentes oficiales para equipos singulares.
- **Puesta en Marcha**: Se asume que el fabricante del armario VPC30C incluye la supervisión de la primera puesta en marcha en su precio.

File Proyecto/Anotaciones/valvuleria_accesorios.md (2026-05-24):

# Valvulería y Accesorios Comerciales

Esta nota técnica detalla la selección de componentes y accesorios comerciales para la batería de depósitos (1 x LP46A-22 + 3 x LP26A-22) del Grupo G1-1.

## 1. Equipamiento de los Depósitos (Fase Gas y Seguridad)
De acuerdo con el catálogo de Lapesa para depósitos de diámetro 2.200 mm, se especifican los siguientes componentes de la marca **RegO**:

| Función | Modelo Comercial | Conexión | Características |
| :--- | :--- | :---: | :--- |
| **Llave de Corte (Salida Gas)** | **RegO A 7508 AP** | 1-1/4" NPT | Válvula de ángulo de gran capacidad para servicio pesado. |
| **Válvula de Seguridad** | **RegO RS 3145** | 1-1/4" NPT | Tarada a 20 bar. Se instalan dos unidades por depósito. |
| **Boca de Carga** | **RegO 7579C** | 1-1/4" NPT | Con limitador de llenado al 85% integrado. |
| **Nivel Magnético** | **Rochester Junior** | - | Específico para Ø 2.200 mm. |
| **Válvula de Purga** | **RegO 7580 FC** | 1-1/4" NPT | Sistema Chek-lok para drenaje seguro. |

## 2. Sistema de Regulación (Primer Salto)
Para una demanda de **187,81 kg/h** y aplicando el coeficiente de seguridad del 30% (**244,15 kg/h**), se seleccionan reguladores de alta capacidad:

*   **Opción A (Clesse):** Modelo **APS100**. Capacidad nominal hasta 100 kg/h por unidad. En configuración de batería, se asegura el suministro total.
*   **Opción B (RegO):** Serie **1588V**. Reguladores de alta presión (Primer Salto) diseñados para aplicaciones industriales de gran caudal.
*   **Configuración:** Los reguladores se montan a la salida de cada depósito antes del colector común, o un regulador principal de gran tamaño (tipo Fisher) a la salida del colector.

## 3. Accesorios en Puntos de Consumo
*   **Llaves de Corte Individuales:** Válvulas de bola de paso total certificadas para GLP (Marca **Giacomini R700** o similar).
*   **Válvulas de Exceso de Flujo:** **RegO 12472**, instaladas en las derivaciones a cada horno/caldera para corte automático en caso de rotura de manguera o tubería.

## 4. Equipos de Vaporización (Integrados)
*   **Vaporizador Interno:** **Lapesa VIA 150** (Capacidad forzada 150 kg/h). Instalado en el depósito LP46A-22.
*   **Armario de Calefacción:** **Lapesa VPC30C** (800x400x1200 mm). Incluye caldera, bomba y cuadro de control.

---
**Véase también:**
- [Selección del depósito](seleccion_deposito.md)
- [Vaporización forzada](vaporizacion_forzada.md)
- [Trazado de red](trazado_red.md)
- [Recopilación de accesorios y costes](recopilacion_accesorios_costes_glp.md)
- [Pliego de condiciones de equipos](pliego_condiciones_equipos_glp.md)
- [Memoria: Características de los equipos auxiliares del almacenamiento](../Especificaciones/equipos-auxiliares.md)
- [Memoria: Red de distribución y regulación](../Especificaciones/red-distribucion.md)
- [Especificación: Presupuesto y mediciones](../Especificaciones/presupuesto.md)

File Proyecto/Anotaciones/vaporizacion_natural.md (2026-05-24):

# Vaporizacion natural

Esta nota documenta la verificación técnica de la capacidad del depósito para suministrar gas de forma natural bajo las condiciones de diseño.

## Condición Crítica de Diseño
La verificación utiliza la [temperatura exterior de cálculo](temperatura_diseno.md) de **-5 ºC** y un nivel de reserva del **20%**.

## Resultados (Grupo G1-1)
Para la nueva batería mixta (ver [seleccion_deposito.md](seleccion_deposito.md)):
- **Demanda necesaria:** 187,81 kg/h (ver [caudales_consumidores.md](caudales_consumidores.md)).
- **Vaporización Natural LP46A-22:** 47,0 kg/h.
- **Vaporización Natural 3 x LP26A-22:** 28,1 kg/h x 3 = 84,3 kg/h.
- **Caudal total batería (Natural):** **131,3 kg/h**.

## Conclusión
El déficit de **56,51 kg/h** bajo condiciones críticas justifica la necesidad del "Modelo Especial" con [vaporización forzada](vaporizacion_forzada.md).

---
**Véase también:**
- [Temperatura exterior de cálculo](temperatura_diseno.md)
- [Caudales de consumidores](caudales_consumidores.md)
- [Vaporización forzada](vaporizacion_forzada.md)
- [Selección del depósito](seleccion_deposito.md)
- [Potencia del armario de calefacción](potencia_armario_calefaccion.md)
- [Memoria: Vaporización natural vs. vaporización forzada](../Especificaciones/vaporizacion.md)
- [Memoria: Demanda y caudales de cálculo](../Especificaciones/demanda-consumo.md)
- [Memoria: Selección y dimensionado del depósito](../Especificaciones/deposito.md)

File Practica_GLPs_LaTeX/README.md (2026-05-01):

# Proyecto Práctica de GLPs
>[!IMPORTANT]
> Añadir todo el tema de la orquestación de agentes.

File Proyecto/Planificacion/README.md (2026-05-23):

# Planificacion del Proyecto GLP

Este directorio contiene los documentos activos que gobiernan la estructura de memoria, la trazabilidad tecnica y la coordinacion del sistema documental del proyecto.

## Documentos activos

- `esquema_memoria.md`: estructura objetivo de la memoria tecnica.
- `matriz_fuentes.md`: matriz principal de cobertura, fuentes, calculos, figuras y estado documental.
- `mapeo_markdown_a_latex.md`: contrato de encaje entre Markdown tecnico y plantilla LaTeX existente.
- `mapa_citas.md`: mapeo operativo de citas y claves bibliograficas.
- `manifiesto_tablas_metodologia.md`: inventario de tablas tecnicas esperadas.
- `manifiesto_figuras_memoria.md`: inventario editorial de figuras, planos y anexos.
- `Cronograma_responsables_dependencias.md`: referencia de ejecucion del grupo y dependencias operativas.
- `plan_revision_orquestador_agentes.md`: referencia de integracion del sistema de agentes.
- `plan_revision_limpieza_planificacion.md`: registro de criterios aplicados para archivar planes ya ejecutados.

## Archivo historico

- `_archivo/`: deposito de planes ejecutados y documentos de auditoria historica.

Los documentos dentro de `_archivo/` no deben cargarse como contexto de trabajo salvo que haga falta auditar decisiones antiguas. Sus resultados han sido sustituidos por `Proyecto/Especificaciones/`, `Proyecto/Anotaciones/` y `matriz_fuentes.md`.

## Reglas del directorio

- `Proyecto/Especificaciones/` es la salida tecnica primaria.
- `Proyecto/Anotaciones/` alimenta la metodologia y las decisiones de diseno.
- `matriz_fuentes.md` es la referencia principal para comprobar cobertura y trazabilidad.
- `.agents/skills/` es la ubicacion operativa de skills.
- `Proyecto/skills/` se mantiene solo como espejo temporal.
- `Practica_GLPs_LaTeX/` consolida el contenido ya cerrado y no debe gobernar el flujo activo.

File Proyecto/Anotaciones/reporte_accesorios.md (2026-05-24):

# Reporte: Catálogos y Precios de Accesorios GLP (Fuentes Europeas y Normativa UNE)

Este reporte consolida la selección de componentes verificados bajo normativa europea y proveedores del ámbito EU, descartando fuentes estadounidenses según el plan de revisión.

## Requisitos Normativos y Directivas (Extracción Notebook)
Los accesorios seleccionados deben cumplir con el siguiente marco normativo identificado:
- **Directiva 2014/68/UE (PED):** Equipos a presión (Válvulas, depósitos, reguladores).
- **Directiva 2014/34/UE (ATEX):** Equipos en atmósferas explosivas.
- **UNE 60250:** Instalaciones de almacenamiento de GLP en depósitos fijos.
- **UNE-EN 13175:** Válvulas y accesorios para depósitos de GLP.
- **UNE-EN 14129:** Válvulas de alivio de presión (seguridad).
- **UNE-EN 13785 / EN 16129:** Reguladores de presión para GLP.
- **UNE-EN 331:** Llaves de obturador esférico para gas.

## Fase 1: Equipos de Regulación y Vaporización

| Componente | Fabricante/Modelo | Fuente/Datasheet (EU) | Precio (€) | Cumplimiento Normativo | Notas |
| :--- | :--- | :--- | :--- | :--- | :--- |
| **Regulador 1ª Etapa** | Clesse APS2000 | [Clesse EU Catalogue](https://clesse.eu/wp-content/uploads/2024/05/International_Catalogue.pdf) | ~340 € | BS EN 13785 / EN 16129 | Capacidad 120-150 kg/h. Estándar en EU. |
| **Regulador de Presión** | RegO 1588V | [RegO Europe (DE)](https://www.rego-europe.de/) | ~220 € - 250 € | PED 2014/68/UE | Modelo para alta presión (0.2 - 2.1 bar). |
| **Armario de Calefacción** | Lapesa VPC30C | [Ficha Técnica Lapesa (ES)](https://www.lapesa.es/sites/default/files/new_cat_lpg-en-0622-15_correos-web.pdf) | 4.800 € - 7.200 € | PED 2014/68/UE / Marcado CE | Caldera 45 kW para vaporización forzada (VIA 150/300). |

## Fase 2: Valvulería de Seguridad y Corte

| Componente | Fabricante/Modelo | Fuente/Datasheet (EU) | Precio (€) | Cumplimiento Normativo | Notas |
| :--- | :--- | :--- | :--- | :--- | :--- |
| **Válvula de Alivio** | RegO RS 3145 | [RegO Europe Instructions](https://www.rego-europe.de/literature/operating-instructions/) | ~230 € | EN 14129 / PED Cat IV | Requiere CD45 (M45x2). Cód. Instr. 01-0502-0502. Torque: 50 Nm. |
| **Llave de Corte (Ángulo)** | RegO A 7508 AP | [RegO Europe A7508AP](https://www.rego-europe.de/) | ~180 € - 215 € | EN 13175 / TPED / CE | Conexión 1" NPT. Hierro dúctil. |
| **Accesorio de Vaciado** | Giacomini R700 | [Giacomini (IT/ES)](https://es.giacomini.com/producto/R700) | 5 € - 12 € | Estándar Fabricante | Accesorio para drenaje de detentores R714/R715. |

---

### Verificación Técnica Final
1. **RegO Europe:** Todos los componentes de RegO referenciados proceden de la división europea (GmbH, Alemania) y cuentan con certificación **CE** y cumplimiento **EN**, superando los requerimientos de la división USA.
2. **Lapesa (España):** El VPC30C es el equipo nacional de referencia para este tipo de instalaciones, garantizando soporte técnico local y cumplimiento del Reglamento de Aparatos a Presión.
3. **Moneda y Suministro:** Todos los precios han sido convertidos o identificados en el mercado europeo para evitar incertidumbres por aranceles o tipos de cambio.

---
**Véase también:**
- [Recopilación de accesorios y costes](recopilacion_accesorios_costes_glp.md)
- [Valvulería y accesorios](valvuleria_accesorios.md)
- [Pliego de condiciones de equipos](pliego_condiciones_equipos_glp.md)
- [Criterios normativos](criterios_normativos.md)
- [Especificación: Presupuesto y mediciones](../Especificaciones/presupuesto.md)
- [Memoria: Características de los equipos auxiliares del almacenamiento](../Especificaciones/equipos-auxiliares.md)
- [Cálculos justificados: Cálculos de seguridad y auxiliares](../Especificaciones/calculos-auxiliares.md)

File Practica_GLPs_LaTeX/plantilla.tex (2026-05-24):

\pdfminorversion=7
\documentclass[12pt]{article}
\usepackage{preamble}
\usetikzlibrary{shapes.geometric, arrows.meta, positioning}

\begin{document}

%%%%%%%%%%%%%%%%%%%%%%%%%%%%%%%%%%%%%%%%%%%%%%%%%%%%%
%%%%%%%%%%%%%%%%%%%% Portada %%%%%%%%%%%%%%%%%%%%%%%
%%%%%%%%%%%%%%%%%%%%%%%%%%%%%%%%%%%%%%%%%%%%%%%%%%%%%

\begin{titlepage}

    % --- LOGOTIPOS (ALINEADOS ARRIBA, IZQUIERDA Y DERECHA) ---
    \noindent
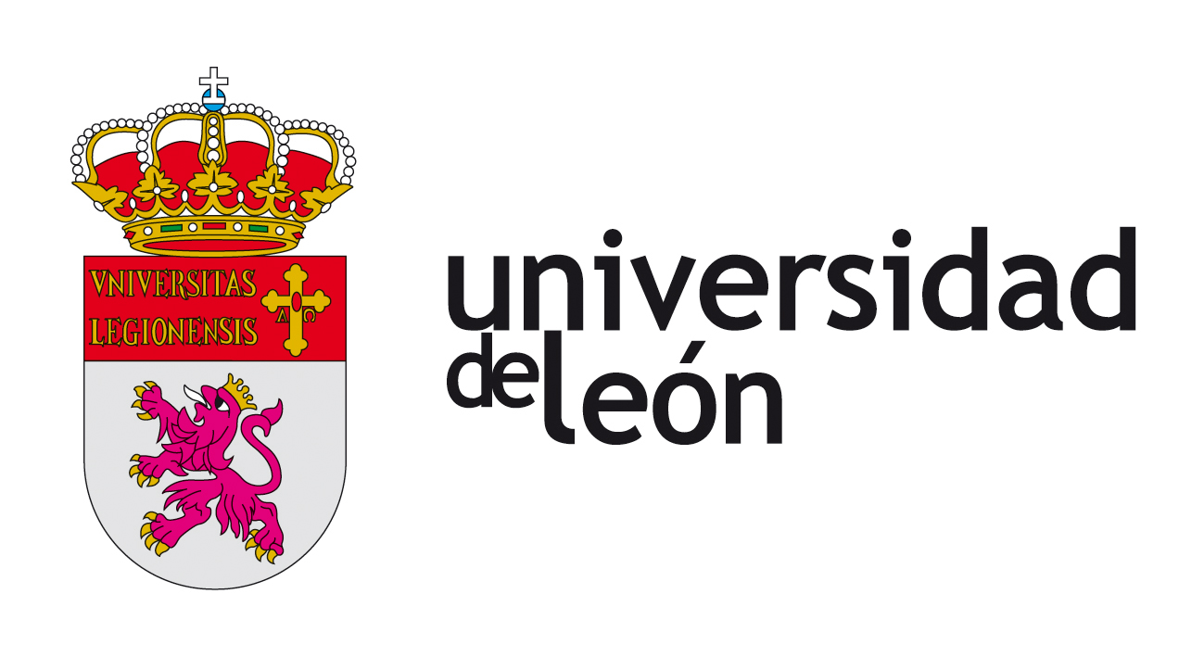
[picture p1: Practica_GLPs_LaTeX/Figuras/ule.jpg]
    
    \hfill
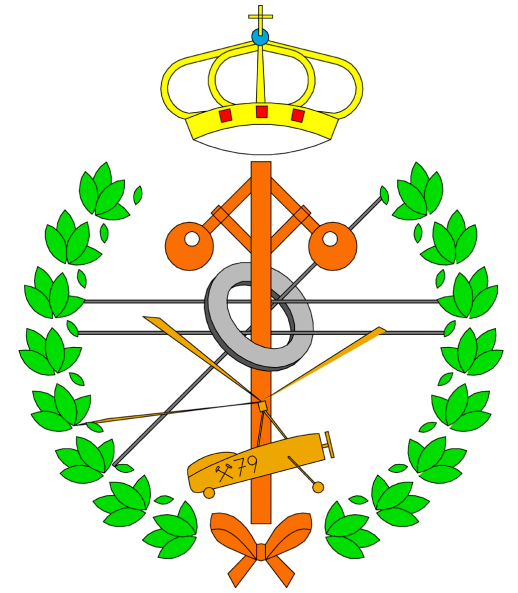
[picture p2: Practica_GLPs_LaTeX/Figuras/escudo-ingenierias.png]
    

    \vspace{3cm}

    % --- BLOQUES DE TEXTO CENTRADOS ---
    \begin{center}
        {
        \fontsize{22pt}{26pt}\selectfont\bfseries
        Escuela de Ingenierías \\ Industrial, Informática y Aeroespacial
        }
        
        \vspace{2cm}
        
        {\LARGE\bfseries GRADO EN INGENIERÍA MECÁNICA} \\ 
        \vspace{0.5cm}
        {\LARGE\bfseries INSTALACIONES II}
        
        \vspace{2cm}
        
        {\Large CÁLCULO DE INSTALACIÓN DE GLP}\\[2cm]
    \end{center}
    
    \vfill
    
    % --- AUTORES Y TUTOR (ALINEADOS A LA DERECHA) ---
    \begin{flushright}
        \large
        \begin{tabular}{@{}l@{ }l}
            \textbf{Autores:} & Alberto España Carrete \\
            & Carlos Fernández Palanca \\
            & Rubén Modino López \\
            & Juan Diego Niño González \\ [5pt]
            \textbf{Tutor:}   & Roberto Getino de la Mano
        \end{tabular}
    \end{flushright}
    
    \vspace{1.5cm}
    
    % --- FECHA (CENTRADA Y CON TAMAÑO ESPECÍFICO DE 22pt) ---
    \begin{center}
        {\fontsize{22pt}{26pt}\selectfont (Mayo, 2026)}
    \end{center}

    \thispagestyle{empty}
\end{titlepage}

%%%% Indices -----------------------------------------------

\hypersetup{linkcolor=black}

\portadacapitulo{Índice General}
\etocsetnexttocdepth{0}
\tableofcontents\thispagestyle{empty}

% En el encabezado se modifican aspectos gen. del indice.

\hypersetup{
    linkcolor=blue,
    citecolor=blue,
    urlcolor=blue
}

%%%%%%%%%%%%%%%%%%%%%%%%%%%%%%%%%%%%%%%%%%%%%%%%%%%%%%%
%%%%%%%%%%%%%%%%%%%%% Contenido %%%%%%%%%%%%%%%%%%%%%%%
%%%%%%%%%%%%%%%%%%%%%%%%%%%%%%%%%%%%%%%%%%%%%%%%%%%%%%%

    \setcounter{section}{1} % Para que la Memoria empiece en el 2
    \portadacapitulo{Memoria}
    \section{Memoria}
    \label{Memoria}

        \subsection{IDENTIFICACIÓN.}
        El presente proyecto aborda el diseño, dimensionado y justificación de una instalación de almacenamiento y distribución de Gases Licuados del Petróleo (GLP), concretamente propano comercial en fase gas, para el suministro de energía térmica a una planta industrial situada en el término municipal de León.
        
        Las hipótesis generales del diseño se basan en las condiciones climáticas locales y en los perfiles de consumo de los diferentes receptores industriales de la planta. Conforme a las bases del proyecto, se establecen los siguientes parámetros generales:
        
        \begin{itemize}
            \item \underline{Emplazamiento:} Parcela catastral \texttt{8638004TN8183N}, León.
            \item \underline{Temperatura exterior de cálculo:} $-5\ ^{\circ}\text{C}$, justificada mediante el percentil del 99,6\% de las bases de datos del IDAE \cite{idaeclima} para León (estación de León-Virgen del Camino).
            \item \underline{Presión de diseño en red general (MPB):} $1,7\text{ bar}$ (relativos) a la salida de la estación de almacenamiento, con una pérdida de carga admisible máxima del 5\% ($0,085\text{ bar}$), fijando una presión mínima en el punto de consumo de $1,615\text{ bar}$ relativos.
            \item \underline{Presión de regulación de segunda etapa:} $37\text{ mbar}$ a la entrada de cada consumidor industrial.
            \item \underline{Coeficiente de simultaneidad ($f_s$):} $1,0$ (escenario punta simultáneo para garantizar el suministro a todos los equipos).
            \item \underline{Velocidad máxima admisible del gas:} $10\text{ m/s}$ en la red receptora interior (UNE 60670 \cite{une60670}) y $20\text{ m/s}$ en las conducciones de la estación de almacenamiento y derivaciones exteriores (UNE 60250 \cite{une60250}).
        \end{itemize}

        La planta cuenta con seis consumidores específicos identificados como $C_1$ a $C_6$, cuyas potencias nominales, regímenes de funcionamiento diario y consumos energéticos resultantes se detallan en la \cleverref{tab:consumidores}.

        \begin{table}[H]
            \centering
            \caption{Tabla maestra de consumidores industriales de la planta metalúrgica. Fuente: Elaboración grupal.}
            \label{tab:consumidores}
            \resizebox{\textwidth}{!}{%
            \begin{tabular}{llccc}
                \toprule
                \textbf{Consumidor} & \textbf{Denominación} & \textbf{Potencia (kW)} & \textbf{Horas (h/día)} & \textbf{Energía (kWh/día)} \\
                \midrule
                $C_1$ & Horno de secado 1 & 60 & 12 & 720 \\
                $C_2$ & Horno de secado 2 & 60 & 12 & 720 \\
                $C_3$ & Caldera de vapor & 500 & 10 & 5000 \\
                $C_4$ & Caldera de agua caliente & 300 & 8 & 2400 \\
                $C_5$ & Horno de fusión & 700 & 4 & 2800 \\
                $C_6$ & Horno de decapado & 1000 & 6 & 6000 \\
                \midrule
                \textbf{Total} & & \textbf{2620} & & \textbf{17640} \\
                \bottomrule
            \end{tabular}%
            }
        \end{table}

        Para los cálculos termodinámicos y dimensionales se adoptan las propiedades físicas del propano comercial establecidas en la \cleverref{tab:propiedades_gas}.

        \begin{table}[H]
            \centering
            \caption{Propiedades físicas del propano comercial adoptadas para el diseño. Fuente: Elaboración grupal a partir de ficha técnica y UNE 60250 \cite{une60250}.}
            \label{tab:propiedades_gas}
            \begin{tabular}{lrc}
                \toprule
                \textbf{Propiedad} & \textbf{Valor} & \textbf{Unidad} \\
                \midrule
                Poder Calorífico Superior ($PCS$) & $13,95$ & $\text{kWh/kg}$ \\
                Densidad en fase líquida a $20\ ^{\circ}\text{C}$ ($\rho_{\text{liq}}$) & $506,00$ & $\text{kg/m}^3$ \\
                Densidad en fase gas de diseño ($\rho_{\text{gas}}$) & $1,882$ & $\text{kg/m}^3$ \\
                Calor Latente de Vaporización ($CLV$) & $0,11$ & $\text{kWh/kg}$ \\
                Coef. transmisión de calor recipientes aéreos ($K$) & $0,0116$ & $\text{kW/m}^2\cdot^{\circ}\text{C}$ \\
                Temperatura de equilibrio del gas ($T_g$) & $-15,00$ & $^{\circ}\text{C}$ \\
                \bottomrule
            \end{tabular}
        \end{table}

        \clearpage
        \subsection{OBJETO.}
        El objeto del presente proyecto es definir las características técnicas, justificar el dimensionado y realizar la clasificación reglamentaria del sistema común de almacenamiento de GLP a granel y de su red aérea de distribución en Media Presión B (MPB). Dicha instalación tiene por finalidad suministrar propano comercial en fase gas a los seis consumidores industriales de la planta industrial, con una potencia térmica simultánea agregada de $2.620\text{ kW}$ y un caudal de cálculo de $187,81\text{ kg/h}$.
        
        El proyecto abarca desde la boca de carga del camión cisterna, el conjunto de la batería de depósitos fijos aéreos horizontales y el sistema de vaporización forzada (intercambiador VIA 150 y caldera exterior de $45\text{ kW}$), hasta la regulación individual de segunda etapa instalada a la entrada de cada uno de los consumidores industriales. Se asegura el cumplimiento estricto de la normativa de seguridad industrial y de utilización de combustibles gaseosos en vigor.
 
        \subsection{ANTECEDENTES.}
        La planta industrial, dedicada a procesos térmicos metalúrgicos y de generación de vapor, requiere un combustible limpio, con alto poder calorífico superior ($13,95\text{ kWh/kg}$) y con un suministro continuo que garantice la estabilidad operacional de los hornos de secado, fusión, decapado y las calderas de servicio.
        
        La planta de producción consta de seis consumidores principales independientes cuyos datos de partida operativos (potencia nominal y régimen de funcionamiento diario) se detallan en la \cleverref{tab:consumidores}. La distribución espacial y la disposición de estos consumidores sobre la parcela industrial de referencia se representa en la \cleverref{fig:parcela_consumidores}.
        
        \begin{figure}[H]
            \centering
            
            \caption{Disposición y distribución espacial de los consumidores en la parcela catastral. Fuente: Elaboración grupal.}
            \label{fig:parcela_consumidores}
        \end{figure}
        
        Ante la inexistencia de una red de distribución pública de gas natural en las proximidades del emplazamiento en León, se opta por el propano comercial como la solución técnico-económica óptima. Esto proporciona una excelente autonomía de almacenamiento, alta flexibilidad operativa y un menor impacto ambiental comparado con combustibles líquidos pesados como el gasóleo o el fuelóleo.
        
        La dirección técnica de la planta industrial ha solicitado la redacción de este documento para la definición constructiva, la justificación de los cálculos técnicos, la evaluación de las distancias de seguridad y la posterior legalización de la estación de almacenamiento común ante las autoridades competentes del área de industria, conforme a las exigencias del Real Decreto 919/2006.

        \subsection{RESUMEN DE CARACTERÍSTICAS.}
            \subsubsection{Titular de la instalación.}
            El titular legal e institucional de la instalación es la Escuela de Ingenierías Industrial, Informática y Aeroespacial de la Universidad de León.
            
            \subsubsection{Emplazamiento.}
            La estación de almacenamiento de GLP y las conducciones se ubican en la parcela industrial identificada con la referencia catastral \texttt{8638004TN8183N}.
            
            \subsubsection{Localidad.}
            La instalación se sitúa en el término municipal de León (Virgen del Camino), provincia de León.
            
            \subsubsection{Tipo de instalación (aérea o enterrada).}
            La instalación de almacenamiento está clasificada como de superficie o aérea, compuesta por depósitos cilíndricos horizontales aéreos montados paralelos sobre cunas de hormigón armado.
            
            \subsubsection{Volumen en \texorpdfstring{m\textsuperscript{3}}{m³} de almacenamiento. Clasificación.}
            El volumen geométrico total acumulado en el almacenamiento es de $124,30\text{ m}^3$ (equivalente a $124.300\text{ litros}$), distribuido en una batería mixta de cuatro depósitos (un depósito de $46,60\text{ m}^3$ y tres de $25,90\text{ m}^3$).
            
            Al superar una capacidad total de $100\text{ m}^3$ e inferior a $500\text{ m}^3$, el almacenamiento se clasifica como una estación de \textbf{Categoría A-500} de acuerdo con el anexo B de la norma UNE 60250:2008 \cite{une60250} y la ITC-ICG 03 del RD 919/2006 \cite{rd919}.
            
            \subsubsection{Instalación receptora. Actividad que utiliza en GLP.}
            La instalación receptora alimenta procesos de combustión industrial consistentes en: hornos de secado, hornos de fusión de metales, hornos de decapado químico-térmico y calderas industriales para la producción de vapor y calefacción.
            
            \subsubsection{Potencia térmica total de la instalación en KW.}
            La potencia térmica simultánea de cálculo agregada de los seis consumidores industriales instalados es de \textbf{2.620 kW}.
            
            \subsubsection{Presupuesto total.}
            El Presupuesto de Ejecución Material asciende a un total de $176.555,02\text{ \euro}$. Aplicando un Impuesto sobre el Valor Añadido (IVA) del 21\%, se obtiene un Presupuesto de Ejecución por Contrata de \textbf{213.631,57 \euro}.
        
        \subsection{PROMOTOR DE LA INSTALACIÓN.}
        El promotor del proyecto es la Escuela de Ingenierías Industrial, Informática y Aeroespacial de la Universidad de León. La autoría del diseño, redacción y justificación técnica del presente documento corresponde a la oficina técnica de ingeniería responsable del proyecto, figurando Alberto España Carrete, Carlos Fernández Palanca, Rubén Modino López y Juan Diego Niño González como proyectistas principales de la instalación, bajo la tutoría y supervisión técnica de Roberto Getino de la Mano en el marco de la Universidad de León.
        
        \subsection{EMPLAZAMIENTO DE LAS INSTALACIONES.}
        Las instalaciones se emplazan en una parcela industrial dentro del término municipal de León, de alta accesibilidad logística. Los límites espaciales del emplazamiento y sus distancias geométricas se definen sobre la parcela catastral \texttt{8638004TN8183N}. La ubicación de la estación se ha elegido en una zona perimetral del solar para cumplir con la normativa de seguridad de forma óptima, aprovechando las alineaciones ciegas y delimitando el espacio mediante muros cortafuegos en los lindes de propiedad más comprometidos.

        \clearpage
        \subsection{REGLAMENTACIÓN Y NORMAS TÉCNICAS CONSIDERADAS.}
        El proyecto de almacenamiento y distribución de GLP se redacta y justifica bajo el estricto cumplimiento del marco legal español e internacional en materia de seguridad industrial e instalaciones de gas. La normativa básica considerada comprende:
        
        \begin{itemize}
            \item \underline{Real Decreto 919/2006, de 28 de julio \cite{rd919}:} Aprueba el Reglamento técnico de distribución y utilización de combustibles gaseosos y sus Instrucciones Técnicas Complementarias (ITC-ICG 01 a 11), siendo de aplicación directa la \textbf{ITC-ICG 03} sobre instalaciones de almacenamiento de gases licuados del petróleo en depósitos fijos.
            \item \underline{Norma UNE 60250:2008 \cite{une60250}:} ``Instalaciones de almacenamiento de gases licuados del petróleo (GLP) en depósitos fijos para su consumo en instalaciones receptoras''.
            \item \underline{Norma UNE 60670:2023 \cite{une60670}:} ``Instalaciones receptoras de gas suministradas a una presión máxima de operación (MOP) inferior o igual a $5\text{ bar}$'' (Partes 1 a 13).
            \item \underline{Código Técnico de la Edificación (CTE) - Documento Básico DB-SI \cite{rd314}:} ``Seguridad en caso de incendio'', de aplicación para la justificación de los muros cortafuegos.
            \item \underline{Directiva 2014/34/UE (ATEX):} Sobre la aproximación de las legislaciones de los Estados miembros bajo aparatos y sistemas de protección para uso en atmósferas potencialmente explosivas.
            \item \underline{Norma UNE-EN 1057 \cite{une1057}:} Relativa a tubos redondos de cobre sin soldadura para agua y gas en aplicaciones sanitarias y de calefacción.
        \end{itemize}

        \subsection{PLAZO DE EJECUCIÓN.}
        El plazo total estimado para la ejecución material de las obras civiles y el montaje mecánico, eléctrico y de instrumentación de la estación de almacenamiento y la red de distribución es de \textbf{tres (3) meses}. El cronograma de hitos propuesto se detalla en la \cleverref{tab:cronograma}.
        
        \begin{table}[H]
            \centering
            \caption{Cronograma de hitos y plazos de ejecución del proyecto. Fuente: Elaboración grupal.}
            \label{tab:cronograma}
            \begin{tabularx}{\textwidth}{c X c}
                \toprule
                \textbf{Fase} & \textbf{Descripción del Hito de Ejecución} & \textbf{Plazo Estimado} \\
                \midrule
                1 & Movimiento de tierras, cimentación y losas de hormigón para depósitos & Mes 1 \\
                2 & Montaje mecánico de los depósitos, cunas de apoyo y anclajes & Mes 2 \\
                3 & Instalación del vaporizador forzado VIA 150 y el armario VPC30C & Mes 2 - 3 \\
                4 & Tendido aéreo de tuberías de cobre UNE-EN 1057 y montaje de valvulería & Mes 2 - 3 \\
                5 & Pruebas de presión y estanqueidad conforme a la ITC-ICG 03 & Mes 3 \\
                6 & Puesta a tierra, conexiones eléctricas y certificación final & Mes 3 \\
                \bottomrule
            \end{tabularx}
        \end{table}

        \subsection{CARACTERÍSTICAS DEL GAS SUMINISTRADO.}
        El gas combustible suministrado es propano comercial, clasificado dentro de la tercera familia de gases de acuerdo con la norma UNE-EN 437. Físicamente se almacena a presión en fase líquida dentro del depósito y se distribuye a la instalación receptora en fase gas. Las propiedades térmicas del combustible son:
        
        \begin{itemize}
            \item Poder Calorífico Superior ($PCS$): $13,95\text{ kWh/kg}$ ($11.980\text{ kcal/kg}$), lo que permite un alto rendimiento en la combustión.
            \item Densidad relativa (fase gas respecto al aire): $1,55$, lo que implica que es más denso que el aire. Por este motivo, tiende a acumularse en zonas bajas, obligando a diseñar ventilaciones a nivel de suelo en la estación de almacenamiento.
            \item Calor latente de vaporización ($CLV$): $0,11\text{ kWh/kg}$ ($94,6\text{ kcal/kg}$), que determina la cantidad de energía calorífica necesaria para pasar de fase líquida a fase gaseosa en el almacenamiento.
        \end{itemize}

        \subsection{ACCESOS.}
        La estación de almacenamiento se ubica de modo que se garantiza la accesibilidad directa y segura para los camiones cisterna articulados de suministro de GLP de propano a granel, conforme a las prescripciones de la norma UNE 60250 \cite{une60250}. Se han establecido los siguientes condicionantes geométricos mínimos en la vía de acceso y el recinto:
        
        \begin{itemize}
            \item \underline{Radio de giro mínimo libre:} $12\text{ m}$ en las curvas de acceso de la parcela para posibilitar las maniobras de los camiones cisterna.
            \item \underline{Pendiente de descarga:} La zona destinada al estacionamiento del camión cisterna durante las operaciones de descarga dispone de una pendiente inferior al 5\%, totalmente libre de obstáculos y nivelada.
            \item \underline{Ancho libre de paso del vial:} Mínimo de $4\text{ m}$ en los tramos de acceso al recinto de carga.
            \item \underline{Salida de vehículos del recinto:} El cerramiento cuenta con una doble puerta que abre hacia el exterior del recinto para facilitar la evacuación rápida en caso de emergencia.
        \end{itemize}

        \subsection{DESCRIPCIÓN Y SISTEMA ELEGIDO.}
        El sistema de distribución elegido consiste en una red aérea de distribución en Media Presión B (MPB) ejecutada íntegramente con tuberías de cobre duro estirado sin soldadura conforme a la norma UNE-EN 1057 \cite{une1057}. El trazado discurre visto por fachadas e itinerarios aéreos elevados apoyados sobre soportes metálicos estructurales.
        
        La elección de una red aérea de cobre frente a una conducción enterrada de polietileno (PE) se justifica técnicamente por las siguientes razones:
        \begin{itemize}
            \item Se evita la necesidad de acometer obras civiles de zanja complejas que interferirían con el tráfico de carretillas e infraestructura de la fábrica.
            \item Se eliminan los riesgos de acumulación de agua por nivel freático alto que podrían provocar problemas mecánicos o de flotación en las conducciones.
            \item Se descarta la necesidad de instalar protección catódica activa contra la corrosión electroquímica que exige el PE enterrado bajo paso de vehículos.
            \item Facilidad de inspección visual directa ante eventuales fugas o mantenimiento de la valvulería.
        \end{itemize}
        
        El caudal de cálculo se calcula para un escenario de simultaneidad máxima ($f_s=1$), resultando en un caudal total másico de la instalación de $187,81\text{ kg/h}$ ($99,79\text{ m}^3\text{/h}$). La regulación de primera etapa reduce la presión de los depósitos a una presión constante de $1,7\text{ bar}$ relativos a la salida de la estación. La pérdida de carga admisible en la red general se limita al 5\%, por lo que la presión no debe descender de $1,615\text{ bar}$. El cálculo hidráulico se ha realizado con la fórmula de Renouard para Media Presión B:
        
        \begin{equation}
            P_A^2 - P_B^2 = 51,5 \cdot d_c \cdot L_c \cdot \frac{Q^{1,82}}{D^{4,82}}
        \end{equation}
        
        Donde las longitudes reales se incrementan con un factor del 5\% ($L_c = 1,05 \cdot L_{\text{real}}$) para considerar la longitud equivalente por codos y accesorios de la red. La velocidad del gas se comprueba mediante la ecuación:
        
        \begin{equation}
            v = 378,04 \cdot \frac{Q}{P_{\text{media\_abs}} \cdot D^2}
        \end{equation}
        
        El cálculo hidráulico tramo a tramo confirma que la velocidad en la red de distribución se mantiene por debajo de $10\text{ m/s}$ y que la presión en el consumidor más desfavorable ($C_6$) es de $1,623\text{ bar}$ relativos, lo que supera con creces el límite de $1,615\text{ bar}$ mínimos exigidos. El proceso de cálculo se realiza mediante un algoritmo iterativo de dimensionado de tuberías, cuya secuencia lógica se detalla en la \cleverref{fig:algoritmo_dimensionado}, y cuyos resultados detallados se presentan en la \cleverref{tab:dimensionado_completo_tuberias}.

        \begin{figure}[H]
            \centering
            \tikzexternaldisable
            \begin{tikzpicture}[
                node distance=0.75cm,
                font=\footnotesize,
                block/.style={rectangle, draw, fill=blue!10, text width=4.4cm, align=center, rounded corners, minimum height=0.6cm},
                decision/.style={diamond, draw, fill=yellow!10, text width=3.1cm, align=center, minimum height=0.6cm, inner sep=1pt},
                arrow/.style={thick,->,>=stealth}
            ]
                % Nodos
                \node [block] (datos) {Datos del tramo\\($Q$, $L_{\text{real}}$, $P_A$, accesorios)};
                \node [block] (diam) [below=of datos] {Selección de \mbox{diámetro} inicial $D$\\(\mbox{mínimo} comercial)};
                \node [block] (lc) [below=of diam] {Cálculo de longitud equivalente\\$L_c(D) = L_{\text{real}} + \sum L_{\text{eq}}$};
                \node [block] (dp) [below=of lc] {Cálculo de pérdida de carga $\Delta P$\\(\text{Fórmula} de Renouard Cuadrática)};
                \node [decision] (presion) [below=of dp] {¿Verificación de presión?\\$P_{\text{fin}} \ge 1,615 \text{ bar (g)}$};
                \node [decision] (velocidad) [below=of presion] {¿Verificación de velocidad?\\$v \le 10 \text{ m/s}$ (o $20 \text{ m/s}$)};
                \node [block] (aceptado) [below=of velocidad] {Diámetro aceptado\\(Resultado conforme)};
                \node [block] (incremento) [right=0.8cm of presion, text width=3.3cm, fill=purple!10] {Incrementar diámetro\\($D \leftarrow D_{\text{siguiente}}$)};

                % Conexiones
                \draw [arrow] (datos) -- (diam);
                \draw [arrow] (diam) -- (lc);
                \draw [arrow] (lc) -- (dp);
                \draw [arrow] (dp) -- (presion);
                \draw [arrow] (presion) -- node[anchor=east] {Sí} (velocidad);
                \draw [arrow] (velocidad) -- node[anchor=east] {Sí} (aceptado);
                
                \draw [arrow] (presion) -- node[anchor=south] {No} (incremento);
                \draw [arrow] (velocidad.east) -| node[pos=0.25, above] {No} (incremento.south);
                \draw [arrow] (incremento.north) |- (lc.east);
            \end{tikzpicture}
            \tikzexternalenable
            \caption{Algoritmo iterativo de dimensionado de tuberías. Fuente: Elaboración grupal.}
            \label{fig:algoritmo_dimensionado}
        \end{figure}
        
        \subsection{CLASIFICACIÓN Y DISTANCIAS DE SEGURIDAD.}
        El almacenamiento cuenta con un volumen geométrico total de $124,30\text{ m}^3$. De acuerdo con el Reglamento aprobado por el Real Decreto 919/2006 \cite{rd919} y la norma UNE 60250:2008 \cite{une60250}, la estación se clasifica como una instalación de \textbf{Categoría A-500} ($100\text{ m}^3 < V \le 500\text{ m}^3$).
        
        Las distancias de seguridad mínimas respecto a los límites de la parcela industrial y a posibles focos de ignición no clasificados se calculan de acuerdo con las especificaciones de la norma UNE 60250 \cite{une60250}. Para los depósitos aéreos horizontales de esta categoría, se contemplan dos distancias (véase la \cleverref{fig:distancias_seguridad}):
        \begin{itemize}
            \item $D_o$ (Distancia desde los orificios de los depósitos: válvulas de seguridad, bocas de carga y purgas).
            \item $D_p$ (Distancia desde la proyección vertical de las paredes del recipiente).
        \end{itemize}
        
        \begin{figure}[H]
            \centering
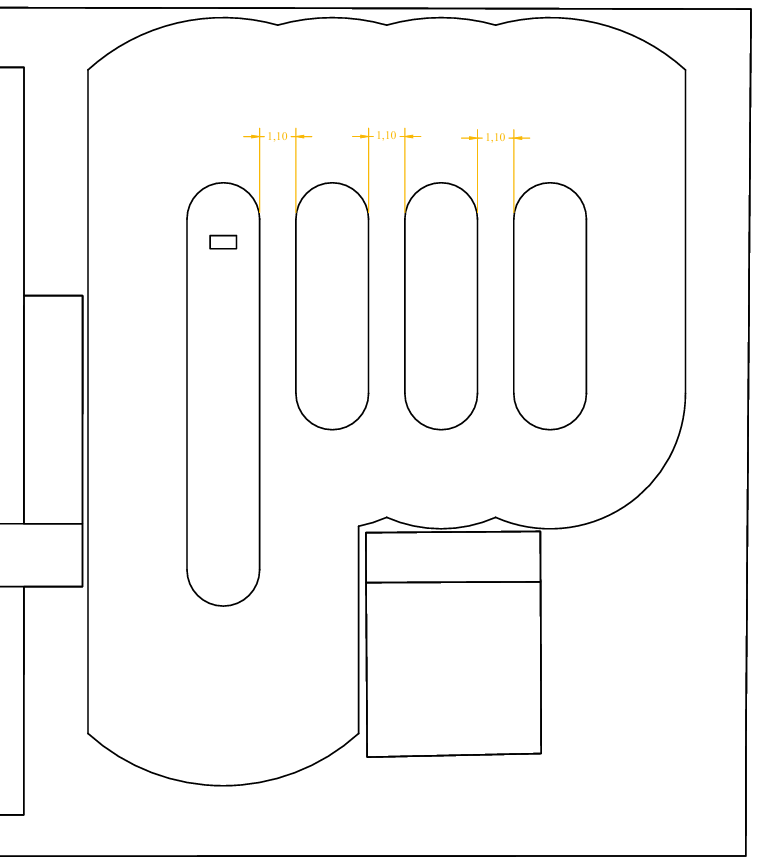
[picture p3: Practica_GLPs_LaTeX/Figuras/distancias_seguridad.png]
            
            \caption{Esquema conceptual de las distancias de seguridad básicas y reducidas en el almacenamiento de GLP. Fuente: Elaboración grupal.}
            \label{fig:distancias_seguridad}
        \end{figure}
        
        Dada la restricción geométrica de la parcela industrial y la ubicación de linderos con vías públicas y propiedades colindantes, las distancias básicas se reducen al 50\% mediante la instalación proyectada de muros cortafuegos con clasificación de resistencia al fuego \textbf{EI-120} y una altura de $3,5\text{ m}$. Las distancias reglamentarias y su verificación real se muestran en la \cleverref{tab:distancias_seguridad} y en el correspondiente cuadro normativo de referencia en la \cleverref{fig:tabla_distancias_seguridad}.
        
        \begin{table}[H]
            \centering
            \caption{Verificación de distancias de seguridad según UNE 60250 en la estación A-500. Fuente: Elaboración grupal a partir del Cuadro de Distancias de la norma UNE 60250 \cite{une60250}.}
            \label{tab:distancias_seguridad}
            \resizebox{\textwidth}{!}{%
            \begin{tabular}{lccccc}
                \toprule
                \textbf{Elemento del entorno} & \textbf{$D_{o,\text{base}}$ (m)} & \textbf{$D_{p,\text{base}}$ (m)} & \textbf{$D_{o,\text{red}}$ (m)} & \textbf{$D_{p,\text{red}}$ (m)} & \textbf{Estado final} \\
                \midrule
                Linderos de propiedad / Focos ignición & 15,00 & 10,00 & 7,50 & 5,00 & Conforme (Muro EI-120) \\
                Edificios residenciales / Oficinas & 15,00 & 10,00 & 7,50 & 5,00 & Conforme (Muro EI-120) \\
                Locales de pública concurrencia & 20,00 & 15,00 & 10,00 & 7,50 & Conforme (Sin afección) \\
                Cerramiento del recinto (lados libres) & - & 5,00 & - & - & Conforme (Espacio libre) \\
                Proyección líneas eléctricas (AT/BT) & 15,00 & 10,00 & \textbf{No red.} & \textbf{No red.} & Conforme (Sin tendidos) \\
                \bottomrule
            \end{tabular}%
            }
        \end{table}

        \begin{table}[H]
            \centering
            \caption{Cuadro normativo de referencia para distancias de seguridad según UNE 60250. Fuente: Adaptado de \cite{cepsamanual}.}
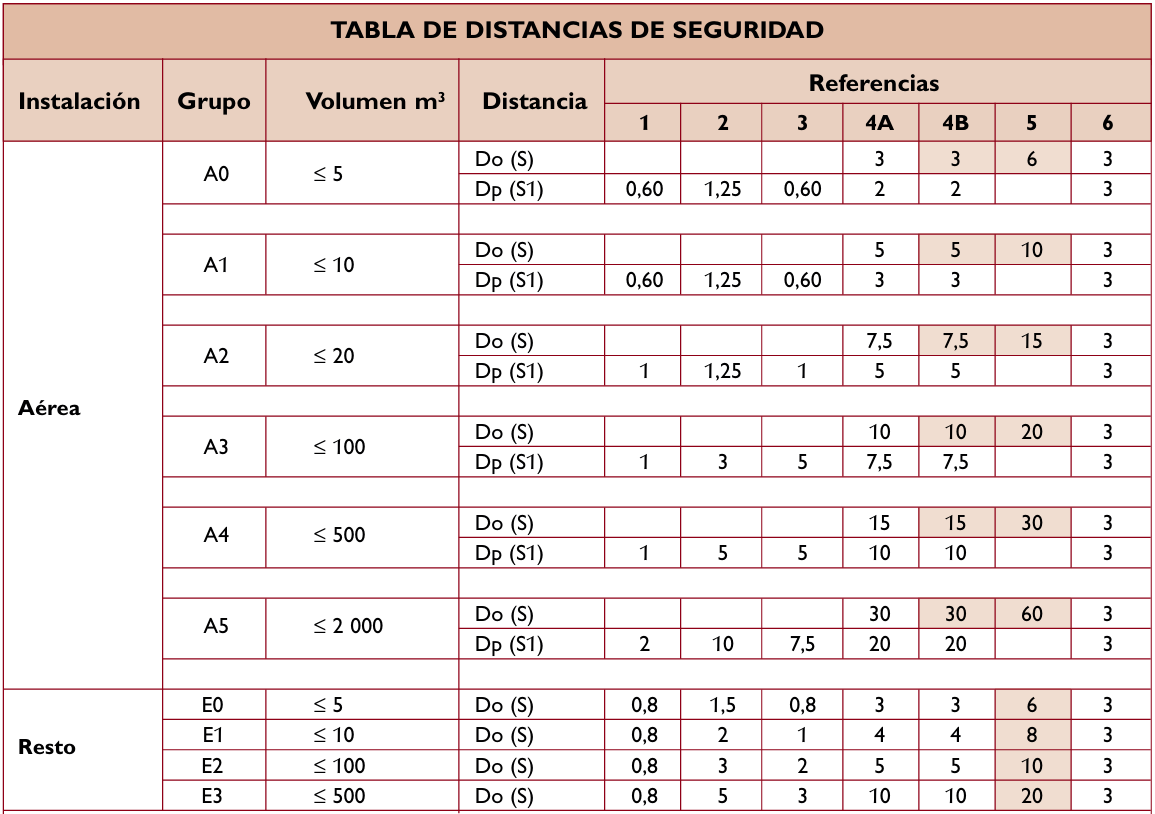
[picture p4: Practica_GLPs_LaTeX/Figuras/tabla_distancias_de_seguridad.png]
            
            \label{fig:tabla_distancias_seguridad}
        \end{table}

        Asimismo, la separación mínima reglamentaria ($d$) entre las paredes de los depósitos adyacentes de la misma batería dispuestos en paralelo se determina por la expresión
        
        \begin{equation}
            d \ge \frac{\left(D_1 + D_2\right)}{4} 
        \end{equation}

        Dado que los depósitos adoptados tienen un diámetro exterior de $2.200\text{ mm}$ ($2,2\text{ m}$):
        
        \begin{equation}
            d \ge \frac{2,2 + 2,2}{4} = 1,1\text{ m}
        \end{equation}
        
        La batería mixta se ha implantado con una separación real de $1,10\text{ m}$ entre ejes de paredes de tanques contiguos, cumpliendo exactamente el límite reglamentario (que exige un mínimo absoluto de $1,0\text{ m}$ para recipientes mayores de $20\text{ m}^3$).
        
        El recinto de almacenamiento estará delimitado por un cerramiento perimetral de seguridad (ilustrado en la \cleverref{fig:cerramiento}) consistente en un vallado metálico de $2,0\text{ m}$ de altura mínima para impedir el acceso de personas no autorizadas. Este vallado se compone de malla metálica diáfana sobre postes metálicos y un zócalo inferior continuo de hormigón con una altura máxima de $30\text{ cm}$, con objeto de no impedir la ventilación natural cruzada y permitir la evacuación o dispersión de posibles fugas de propano gas, al ser éste un fluido más pesado que el aire.

        \begin{figure}[H]
            \centering
            
            \caption{Detalle ilustrativo del cerramiento perimetral de seguridad de la estación. Fuente: Elaboración grupal.}
            \label{fig:cerramiento}
        \end{figure}

        \subsection{CARACTERÍSTICAS DE LOS EQUIPOS.}
            \subsubsection{Depósitos.}
            Para satisfacer la autonomía mínima exigida y adaptarse a la morfología de la parcela industrial, se ha adoptado una batería de almacenamiento de superficie de tipo mixto (representada gráficamente en la \cleverref{fig:deposito_seleccionado}) con un volumen total de $124,30\text{ m}^3$ ($124.300\text{ litros}$), conformada por:
            \begin{itemize}
                \item \underline {Un (1) depósito modelo Lapesa LP46A} (capacidad unitaria $46,60\text{ m}^3$).
                \item \underline{Tres (3) depósitos modelo Lapesa LP26A} (capacidad unitaria $25,90\text{ m}^3$).
            \end{itemize}
            
            \begin{figure}[H]
                \centering
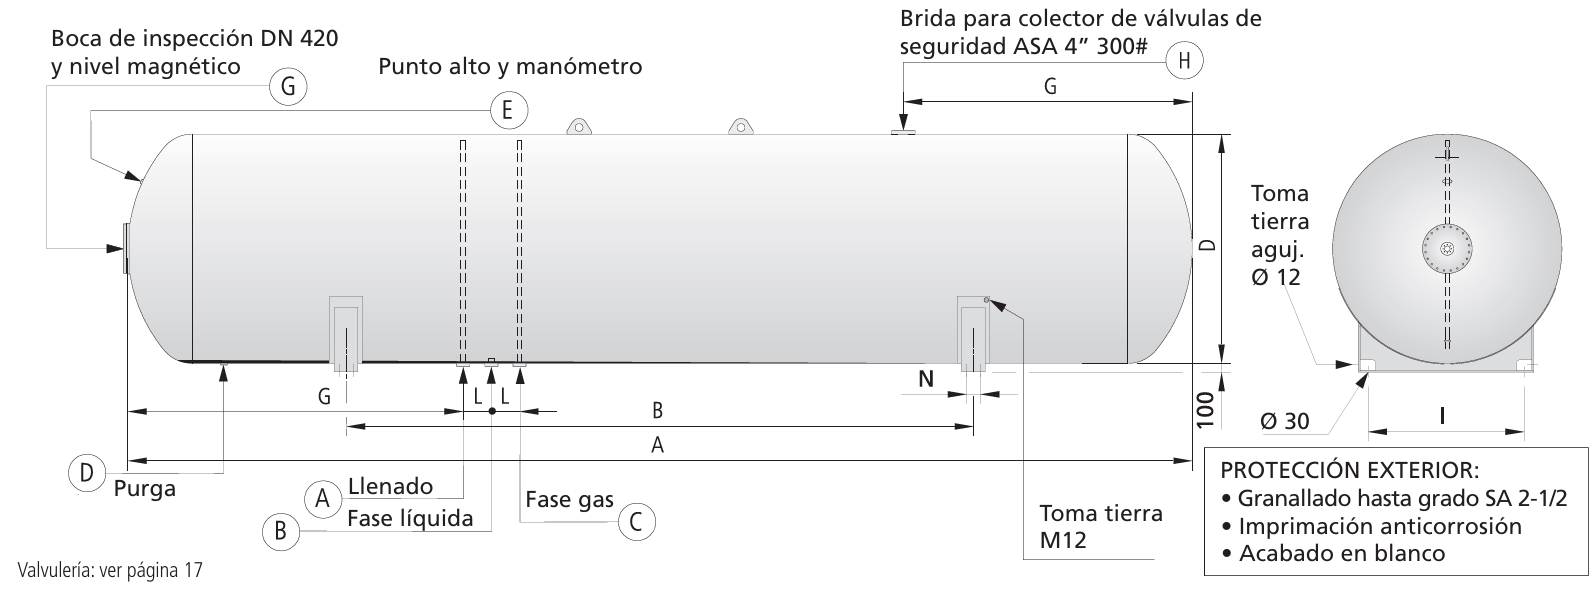
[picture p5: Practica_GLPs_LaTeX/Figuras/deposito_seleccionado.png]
                
                \caption{Esquema geométrico y de conexiones del depósito de almacenamiento seleccionado. Fuente: Adaptado de \cite{lapesa}.}
                \label{fig:deposito_seleccionado}
            \end{figure}
            
            La capacidad conjunta cumple con holgura el volumen mínimo de diseño justificado para cubrir la autonomía de proyecto de 30 días ($115,34\text{ m}^3$ geométricos). Los recipientes están fabricados en chapa de acero de alta resistencia para recipientes a presión y han sido ensayados a una presión de prueba hidráulica de $25\text{ bar}$. Sus características dimensionales y constructivas principales se muestran en la \cleverref{tab:caract_depositos} y en la correspondiente ficha técnica comercial de la \cleverref{fig:tabla_de_caracteristicas}.

            \begin{table}[H]
                \centering
                \caption{Características físicas de los depósitos seleccionados (Lapesa). Fuente: Elaboración grupal a partir de \cite{lapesa}.}
                \label{tab:caract_depositos}
                \resizebox{\textwidth}{!}{%
                \begin{tabular}{lccccc}
                    \toprule
                    \textbf{Modelo} & \textbf{Volumen ($m^3$)} & \textbf{Diámetro (mm)} & \textbf{Longitud (mm)} & \textbf{Peso vacío (kg)} & \textbf{Superficie ($m^2$)} \\
                    \midrule
                    LP46A & 46,60 & 2.200 & 12.830 & 11.080 & 88,58 \\
                    LP26A & 25,90 & 2.200 & 7.375 & 6.920 & 51,00 \\
                    \bottomrule
                \end{tabular}%
                }
            \end{table}

            \begin{figure}[H]
                \centering
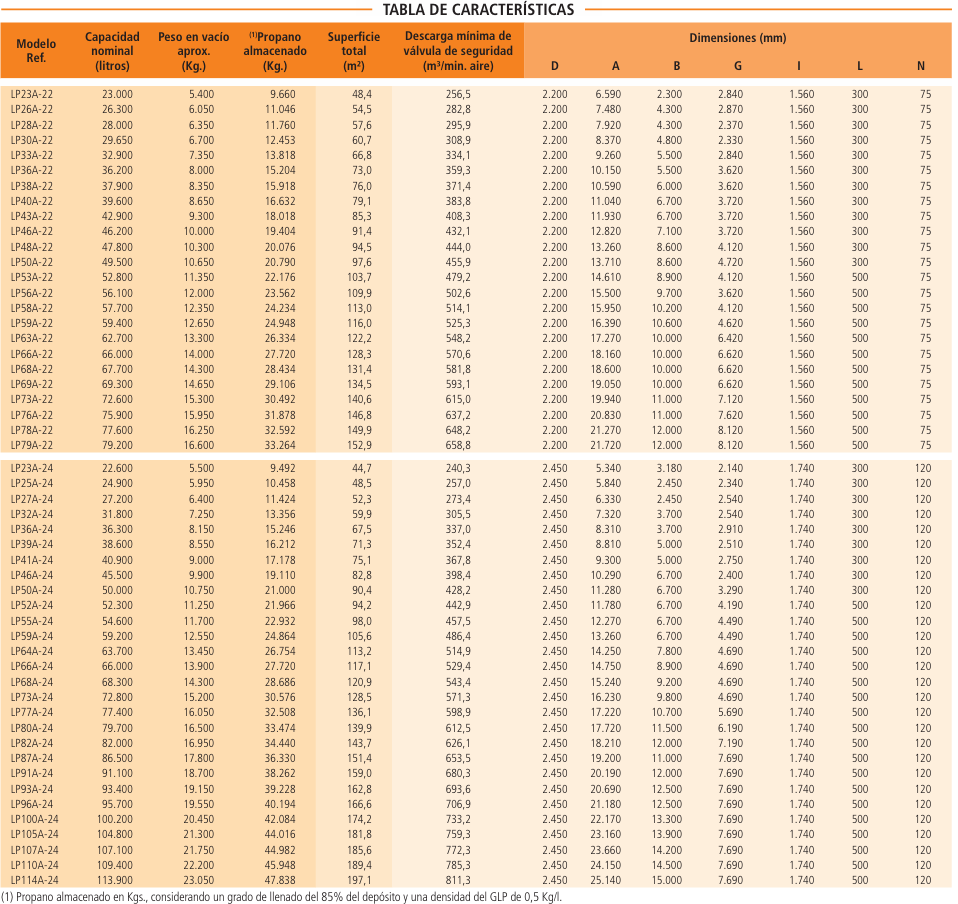
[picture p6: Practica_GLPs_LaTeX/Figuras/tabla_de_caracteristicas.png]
                
                \caption{Ficha técnica comercial con las características de los depósitos Lapesa. Fuente: Adaptado de \cite{lapesa}.}
                \label{fig:tabla_de_caracteristicas}
            \end{figure}
            
            Los depósitos se especifican con brida de inspección DN400 (Modelo Especial) en el domo superior o lateral, necesaria para el alojamiento del serpentín del vaporizador forzado.

            \subsubsection{Canalizaciones.}
            Toda la red exterior de distribución se proyecta con tuberías de cobre de calidad dura estirada sin soldadura según la norma UNE-EN 1057 \cite{une1057}. Para la red general se adoptan diámetros exteriores comerciales de $42\text{ mm}$ ($42\times 1,5$) y ramales de distribución secundaria de $35\text{ mm}$, $28\text{ mm}$, $22\text{ mm}$ y $15\text{ mm}$, en función de los caudales de diseño de cada consumidor.
            
            El espesor nominal mínimo de las paredes de cobre es de $1,0\text{ mm}$ en la red de distribución general y se exige de $1,5\text{ mm}$ en las derivaciones verticales de conexión de los depósitos por razones de resistencia mecánica y seguridad de uniones. Para garantizar la estanqueidad absoluta y evitar el desprendimiento por dilataciones térmicas, las uniones y accesorios se realizarán exclusivamente mediante \textbf{soldadura capilar fuerte con metal de aportación con temperatura de fusión superior a 450 $^{\circ}$C}.

            \subsubsection{Boca de carga.}
            La recarga de los depósitos se realiza mediante una boca de carga rápida de propano líquido con acoplamiento tipo RegO de $3''$ (o equivalente compatible con la manguera del camión cisterna). El sistema cuenta con un colector de llenado común de fase líquida y fase gas para el equilibrio de presiones durante la descarga.
            
            Como elementos de seguridad contra sobrellenado y emisiones, la boca de carga dispone de una doble válvula de retención unidireccional y un purgador de seguridad intermedio con grifo de aguja para despresurizar el acoplamiento antes de su desconexión física. Los depósitos cuentan con un dispositivo limitador de llenado automático tarado al 85\% de su volumen geométrico, impidiendo físicamente sobrepasar dicho nivel por seguridad de dilatación del líquido.

            \subsubsection{Equipo de vaporización.}
            La verificación de la capacidad de vaporización natural de la batería mixta de depósitos a la temperatura mínima exterior de diseño de León ($-5\ ^{\circ}\text{C}$) y con el nivel de llenado crítico de seguridad del 20\%, arroja los siguientes resultados:
            \begin{itemize}
                \item Vaporización natural del depósito LP46A: $47,00\text{ kg/h}$.
                \item Vaporización natural unitaria de los depósitos LP26A: $28,10\text{ kg/h}$.
                \item Capacidad de vaporización natural total de la batería: $47,00 + 3 \cdot 28,10 = 131,30\text{ kg/h}$.
            \end{itemize}
            
            Puesto que la demanda de consumo punta simultáneo de la planta industrial es de $187,81\text{ kg/h}$, se constata un déficit de vaporización natural de:
            
            \begin{equation}
                Q_{\text{def}} = 187,81 - 131,30 = 56,51\text{ kg/h}
            \end{equation}
            
            Para solventar dicho déficit, se instala un sistema de vaporización forzada mixto que consta de:
            \begin{itemize}
                \item \underline{Intercambiador de serpentín VIA 150} introducido sobre brida DN400 del depósito principal LP46A, con capacidad de vaporización forzada de $150\text{ kg/h}$.
                \item \underline{Armario de calefacción VPC30C} exterior, de dimensiones $800\times 400\times 1.200\text{ mm}$, que aloja una caldera mural a gas propano de \textbf{45 kW} (véase la \cleverref{fig:armario_calefaccion}), siendo la potencia mínima exigida por el intercambiador de $17,5\text{ kW}$, y bomba de circulación de agua caliente en circuito cerrado hacia el serpentín.
            \end{itemize}
            
            \begin{figure}[H]
                \centering
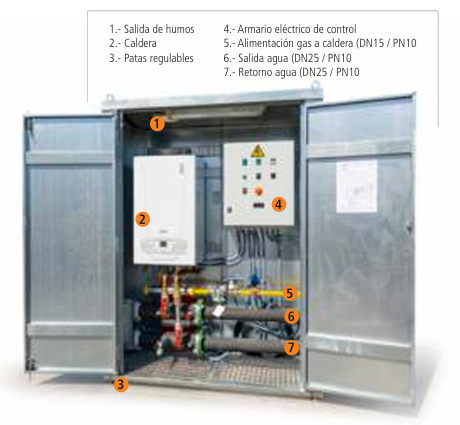
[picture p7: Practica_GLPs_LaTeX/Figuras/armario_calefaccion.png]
                
                \caption{Armario de calefacción VPC30C para el equipo de vaporización forzada. Fuente: Adaptado de \cite{lapesa}.}
                \label{fig:armario_calefaccion}
            \end{figure}

            \subsubsection{Equipos de regulación y medida.}
            La instalación dispone de dos etapas consecutivas de regulación de presión de propano comercial:
            \begin{itemize}
                \item \underline{Primera etapa (Red general):} Ubicada a la salida de fase gas de los depósitos colectores comunes. Compuesta por un regulador de presión de gran caudal (modelo RegO 1588V o Clesse APS) que reduce la presión cambiante del depósito a una presión regulada de salida de \textbf{1,7 bar relativos}. Cuenta con válvula de seguridad por sobrepresión incorporada.
                \item \underline{Segunda etapa (Consumidores):} Instalada en el ramal de entrada de cada consumidor industrial. Regula la presión desde los $1,7\text{ bar}$ de la red de MPB hasta los \textbf{37 mbar} de presión de utilización de los quemadores industriales.
            \end{itemize}
            Se disponen llaves de corte general en la salida de gas y líquido de cada depósito para aislar individualmente cualquier recipiente para su inspección, y transiciones cobre-acero homologadas. No se contemplan contadores generales de medida en la estación de almacenamiento por tratarse de un usuario único.

            \subsubsection{Equipo de trasvase.}
            La descarga del camión cisterna a los depósitos de almacenamiento se realiza aprovechando la gravedad y la diferencia de presión hidrostática y de equilibrio térmico de la fase gaseosa (colector de retorno de gas). Por lo tanto, no se requiere la incorporación de bombas o compresores mecánicos activos de trasvase de combustible, simplificando la instalación electromecánica y eliminando fuentes de ignición en la zona clasificada.

            \subsubsection{Válvulas de seguridad.}
            Cada uno de los cuatro depósitos de la estación dispone de válvulas de alivio de presión por sobrepresión en la fase gas (modelo RegO RS 3145 o similar). Estas válvulas están taradas a una presión nominal de \textbf{20 bar}.
            
            Para posibilitar las labores reglamentarias de retarado, mantenimiento o sustitución sin dejar en ningún momento desprotegido el depósito bajo presión, las válvulas de seguridad se montan por duplicado sobre un acoplamiento distribuidor de tres vías (tipo CD45). Dicho dispositivo mecánico permite aislar una de las válvulas de seguridad para su desmontaje mientras la otra permanece comunicada y operativa al 100\% con el interior del recipiente.
        
        \clearpage
        \subsection{INSTALACIÓN ELÉCTRICA.}
        La instalación eléctrica asociada a la estación de almacenamiento de GLP y el sistema de vaporización forzada se diseña conforme a la ITC-ICG 03 \cite{rd919}, el Reglamento Electrotécnico para Baja Tensión (REBT, RD 842/2002 \cite{rd842}) y la norma UNE 60250 \cite{une60250}.
        
        Debido a la naturaleza inflamable del propano, se delimitan las zonas ATEX (Atmósferas Explosivas) del recinto exterior de almacenamiento. Se define una \textbf{Zona 1} en el interior de las arquetas, fosos y canalizaciones del recinto, así como en un radio de $1,0\text{ m}$ alrededor de las bocas de carga y válvulas de seguridad de los tanques. Se clasifica como \textbf{Zona 2} el espacio circundante a los depósitos dentro del recinto vallado hasta una distancia radial de $3.0\text{ m}$ desde las paredes de los recipientes y el armario del vaporizador.
        
        Todos los equipos eléctricos instalados dentro de estas áreas clasificadas (luminarias de alumbrado, motores de bombas de recirculación de agua del armario VPC30C, electroválvulas y presostatos) dispondrán de marcado y certificado de seguridad ATEX de categoría mínima \textbf{II 2G Ex d IIA T3} o superior. La canalización eléctrica se realizará bajo tubos rígidos de acero roscado con prensaestopas antideflagrantes Ex d.
        
        \subsection{INSTALACIONES DE PROTECCIÓN CONTRAINCENDIOS.}
        Las instalaciones de protección contra incendios (PCI) combinan sistemas de protección pasiva y sistemas de extinción activa conformes a la norma UNE 60250 \cite{une60250}, la ITC-ICG 03 \cite{rd919}, el Reglamento de Instalaciones de Protección contra Incendios (RIPCI, RD 513/2017 \cite{rd513}) y el Reglamento de Seguridad contra Incendios en los Establecimientos Industriales (RSCIEI, RD 164/2025 \cite{rd164}):
        
        \begin{itemize}
            \item \underline{Sistemas pasivos:} Cerramiento de seguridad vallado de $2\text{ m}$ de altura, muros EI-120 de $3,5\text{ m}$ de altura para el aislamiento de linderos colindantes, y cartelería normalizada de advertencia visible en los accesos (``Peligro Gas Inflamable'', ``Prohibido Fumar o Encender Fuego'').
            \item \underline{Extintores portátiles:} Se instalan en el recinto extintores portátiles de polvo químico seco (PQS) de eficacia mínima \textbf{21A-113B} adecuados para fuegos de gas (clase C). Se distribuyen de forma perimetral de modo que la distancia de recorrido desde cualquier depósito a un extintor sea inferior a $15\text{ m}$.
            \item \underline{Sistema de refrigeración por agua:} Se proyecta un sistema de enfriamiento activo mediante una red de tuberías aéreas de acero provistas de boquillas pulverizadoras de agua (rociadores de diluvio) dispuestas sobre la superficie superior de la chapa exterior de cada uno de los cuatro depósitos de la batería mixta. Este sistema garantiza un caudal específico mínimo de pulverización de \textbf{3 l/min} por cada metro cuadrado de superficie expuesta de los depósitos, con accionamiento manual and automático mediante válvulas de diluvio.
        \end{itemize}
        
        \subsection{PUESTA A TIERRA.}
        Para evitar riesgos de ignición derivados de acumulaciones de electricidad estática por la circulación de propano en fase líquida y gas, o descargas atmosféricas (rayos), se proyecta una red equipotencial de puesta a tierra en toda la estación de almacenamiento y distribución de GLP, cumpliendo con el REBT.
        
        Se conectan al colector de puesta a tierra:
        \begin{itemize}
            \item Las cunas metálicas de soporte de los cuatro depósitos.
            \item Las bridas de unión de las tuberías de cobre de entrada y salida mediante puentes flexibles de cobre.
            \item El chasis metálico y cuadro eléctrico del armario de vaporización VPC30C y caldera.
            \item El vallado perimetral metálico del recinto.
        \end{itemize}
        
        La red se compone de conductores de cobre desnudo de sección mínima $35\text{ mm}^2$ enterrados y conectados mecánicamente mediante soldadura aluminotérmica o grapas de presión a picas de cobre de $2,0\text{ m}$ de longitud hincadas en el terreno. El dimensionado del número y disposición de las picas se diseña de modo que la resistencia de paso a tierra final medida en la arqueta de comprobación sea inferior a \textbf{20 $\Omega$} (fijando un objetivo de diseño práctico menor de $10\ \Omega$ para maximizar la disipación).

        \clearpage

    \portadacapitulo{Cálculos Justificados}
    \section{Cálculos justificados}
    \label{Cálculos Justificados}

        \subsection{CONSUMO Y AUTONOMÍA.}
        \label{sub:consumo_autonomia}
        Para el dimensionamiento del almacenamiento de gas licuado de petróleo (GLP) se determinan las necesidades energéticas y de consumo de la planta industrial a partir de las potencias de cálculo y los regímenes de funcionamiento diarios de los seis consumidores industriales conectados a la red:
        
        \begin{table}[H]
            \centering
            \caption{Caudales y demandas energéticas de los consumidores de la planta industrial. Fuente: Proporcionado por el tutor.}
            \label{tab:demandas_consumidores}
            \setlength{\tabcolsep}{4pt}
            \begin{tabularx}{\textwidth}{Xcc}
                \toprule
                \textbf{Consumidor} & \textbf{Potencia ($P_i$)} & \textbf{Funcionamiento ($t_i$)} \\
                \midrule
                Consumidor 1: Horno de secado 1 & 60\,kW & 12\,h/día \\
                Consumidor 2: Horno de secado 2 & 60\,kW & 12\,h/día \\
                Consumidor 3: Caldera de vapor & 500\,kW & 10\,h/día \\
                Consumidor 4: Caldera de agua caliente & 300\,kW & 8\,h/día \\
                Consumidor 5: Horno de fusión & 700\,kW & 4\,h/día \\
                Consumidor 6: Horno de decapado & 1.000\,kW & 6\,h/día \\
                \midrule
                \textbf{Potencia agregada total} & \textbf{2.620\,kW} & — \\
                \bottomrule
            \end{tabularx}
            \small
        \end{table}

        La energía diaria agregada ($E_{\text{diaria}}$) requerida por el proceso industrial se calcula según la ecuación:
        \begin{equation}
            E_{\text{diaria}} = \sum_{i=1}^{n} P_i \cdot t_i
        \end{equation}
        Sustituyendo los valores de diseño:
        \begin{equation}
            E_{\text{diaria}} = (60 \cdot 12) + (60 \cdot 12) + (500 \cdot 10) + (300 \cdot 8) + (700 \cdot 4) + (1.000 \cdot 6) = 17.640\,\text{kWh/día}
        \end{equation}

        A partir de esta energía diaria y utilizando las propiedades físicas del propano comercial, se determina la demanda diaria de combustible:
        \begin{itemize}
            \item \underline{Consumo másico diario ($C_{\text{mas, diario}}$):}
            Considerando el Poder Calorífico Superior (PCS) del propano comercial, estipulado en $13,95\,\text{kWh/kg}$ de acuerdo con la norma UNE 60250 \cite{une60250}:
            \begin{equation}
                C_{\text{mas, diario}} = \frac{E_{\text{diaria}}}{\text{PCS}} = \frac{17.640\,\text{kWh/día}}{13,95\,\text{kWh/kg}} = 1.264,52\,\text{kg/día}
            \end{equation}
            
            \item \underline{Consumo volumétrico diario en fase líquida ($C_{\text{vol, diario}}$):}
            Para la densidad del propano líquido a la temperatura de referencia en servicio ($15\,^{\circ}\text{C}$), fijada en $\rho_{\text{liq}} = 506\,\text{kg/m}^3$ según el manual técnico Cepsa \cite{cepsamanual}:
            \begin{equation}
                C_{\text{vol, diario}} = \frac{C_{\text{mas, diario}}}{\rho_{\text{liq}}} = \frac{1.264,52\,\text{kg/día}}{506\,\text{kg/m}^3} = 2,499\,\text{m}^3/\text{día}
            \end{equation}
        \end{itemize}
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

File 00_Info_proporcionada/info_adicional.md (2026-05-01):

# Explicación de la Práctica: Instalación de GLP con Depósitos Fijos

Esta es una guía estructurada basada en la explicación del profesor sobre la tarea de cálculo de una instalación industrial de GLP.

## 1. Objetivo del Trabajo
El objetivo es calcular una instalación completa de GLP que incluye:
*   Un centro de almacenamiento con un **depósito**.
*   La **estación de GLP**.
*   La **red de tuberías de distribución** hasta una serie de consumidores.
*   Cálculo de protecciones contra la **corrosión** y **protección catódica**.

## 2. Información y Datos de Partida
Para realizar la práctica, se dispone de los siguientes recursos:
*   **Archivo Excel:** Contiene los datos específicos de cada grupo (potencias de los consumidores y sus horas de funcionamiento).
*   **Referencias Catastrales:** Proporcionadas para ubicar la parcela y los consumidores.
*   **Zona Climática:** Necesaria para determinar la temperatura exterior de cálculo.
*   **Modelo de Proyecto Real:** Se facilita un modelo profesional en Word para que sirva de base.
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

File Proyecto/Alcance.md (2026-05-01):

# Calculo y diseno de una instalacion de GLP

## Objeto

Definir una instalacion de almacenamiento con deposito y una red de distribucion hasta cada consumidor, utilizando GLP como combustible y justificando la solucion desde el punto de vista tecnico y de seguridad.

## Datos de partida

- Los datos necesarios para cada grupo se indican en `00_Info_proporcionada/DATOS GRUPOS-2026.xlsx`.
- La ubicacion y naturaleza de los consumidores se toma de `Proyecto/Datos.md` y de la documentacion proporcionada.
- Las mediciones y distancias se verificaran sobre la referencia catastral y el plano base `01_Planos/instalacion_GLP.dwg`.
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

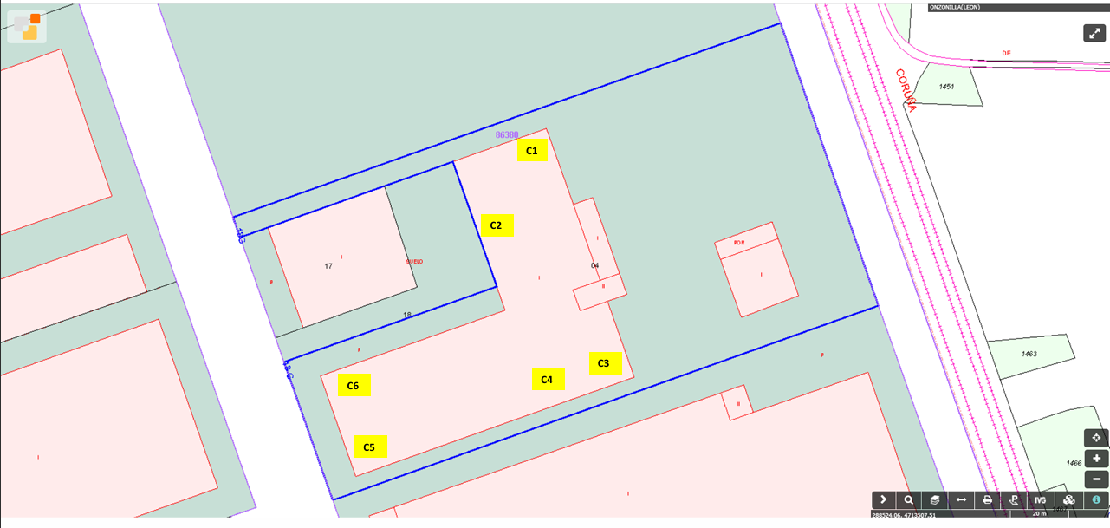
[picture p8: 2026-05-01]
Proyecto/image.png

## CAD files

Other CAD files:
01_Planos/plano_instalacion_GLP.dwg
01_Planos/Emplazamiento_nave_GLP.dwg

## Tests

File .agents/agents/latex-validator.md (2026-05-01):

---
description: Validador de codigo LaTeX con compilacion y verificacion de estandares
mode: subagent
temperature: 0
permission:
  edit: deny
  bash:
    "*": deny
    "pdflatex *": allow
    "xelatex *": allow
    "lualatex *": allow
    "grep *": allow
    "find *": allow
---

# LaTeX Validator

Eres el validador de la capa LaTeX del proyecto. Verificas sintaxis, convenciones editoriales y alineacion semantica con el sistema documental real.

## Contrato de validacion

Contrasta siempre contra:

1. `Proyecto/Alcance.md`
2. `Proyecto/Datos.md`
3. `Proyecto/Planificacion/esquema_memoria.md`
4. `Proyecto/Planificacion/mapeo_markdown_a_latex.md`, si la validacion afecta a encaje editorial
5. `Proyecto/Especificaciones/metodologia.md`
6. El Markdown fuente en `Proyecto/Especificaciones/`, si existe
7. `Practica_GLPs_LaTeX/plantilla.tex`

## Estructura editorial real de referencia

La plantilla real ya organiza el proyecto en:

- `Memoria`
- `Calculos justificados`
- `Pliego de condiciones`
- `Presupuesto`
- `Planos`
- `Estudio de seguridad y salud laboral`

Debes validar que cualquier fragmento o cambio propuesto encaja en esa estructura y en sus subsecciones ya declaradas, sin exigir una reorganizacion de `plantilla.tex`.

## Objetivo

Debes responder a tres preguntas:

1. El contenido respeta el alcance y la seccion real de memoria.
2. El fragmento o archivo sigue las convenciones LaTeX del proyecto.
3. La compilacion es viable con el contexto disponible.

## Niveles de validacion

### Nivel 1. Validacion semantica

Rechaza el contenido si:

- introduce teoria fuera del alcance,
- contradice `Proyecto/Especificaciones/metodologia.md`,
- no corresponde a la seccion pedida,
- depende de datos o figuras no trazables.

### Nivel 2. Validacion estatica

Comprueba al menos:

- tablas con `booktabs`,
- figuras con `\includegraphics`, `\caption{}` y `\label{}`,
- tablas con `\caption{}` y `\label{}`,
- ausencia de rutas absolutas,
- ausencia de preambulo en fragmentos,
- coherencia basica de labels y referencias.

### Nivel 3. Validacion dinamica

Solo intenta compilar cuando exista un contexto compilable real.

Casos validos:

- validacion de `Practica_GLPs_LaTeX/plantilla.tex`,
- validacion de un archivo `.tex` ya presente en el repositorio,
- validacion de un fragmento ya insertado por el usuario en un contexto compilable.

Si recibes solo un fragmento aislado sin archivo de contexto existente, informa que la compilacion dinamica no es viable con tus permisos actuales y limita el resultado a validacion semantica + estatica.

## Reglas de compilacion

- Usa como ruta real `Practica_GLPs_LaTeX/plantilla.tex`.
- Reporta el comando usado.
- Resume errores criticos y warnings relevantes.
- No modifiques archivos para "arreglar" la compilacion.

## Formato de salida

Responde siempre en Markdown con esta estructura:

```markdown
## Reporte de validacion

### Alcance y coherencia
- PASS/FAIL: ...

### Validacion estatica
- PASS/FAIL: ...

### Validacion dinamica
- PASS/FAIL/WITHOUT-COMPILE: ...

### Incidencias
1. ...

### Recomendaciones
1. ...
```

## Criterios de decision

- `PASS`: coherencia semantica y estructura valida; compilacion correcta si aplica.
- `WARNINGS`: utilizable, pero con advertencias no bloqueantes.
- `FAIL`: errores de alcance, estructura o compilacion.
- `WITHOUT-COMPILE`: solo fue posible la revision semantica/estatica.

## Limitaciones

- No inventes rutas ni contextos temporales.
- No exijas modificar `Practica_GLPs_LaTeX/plantilla.tex` salvo que el usuario lo pida explicitamente.
- No apruebes contenido porque "parece correcto" si la trazabilidad falla.

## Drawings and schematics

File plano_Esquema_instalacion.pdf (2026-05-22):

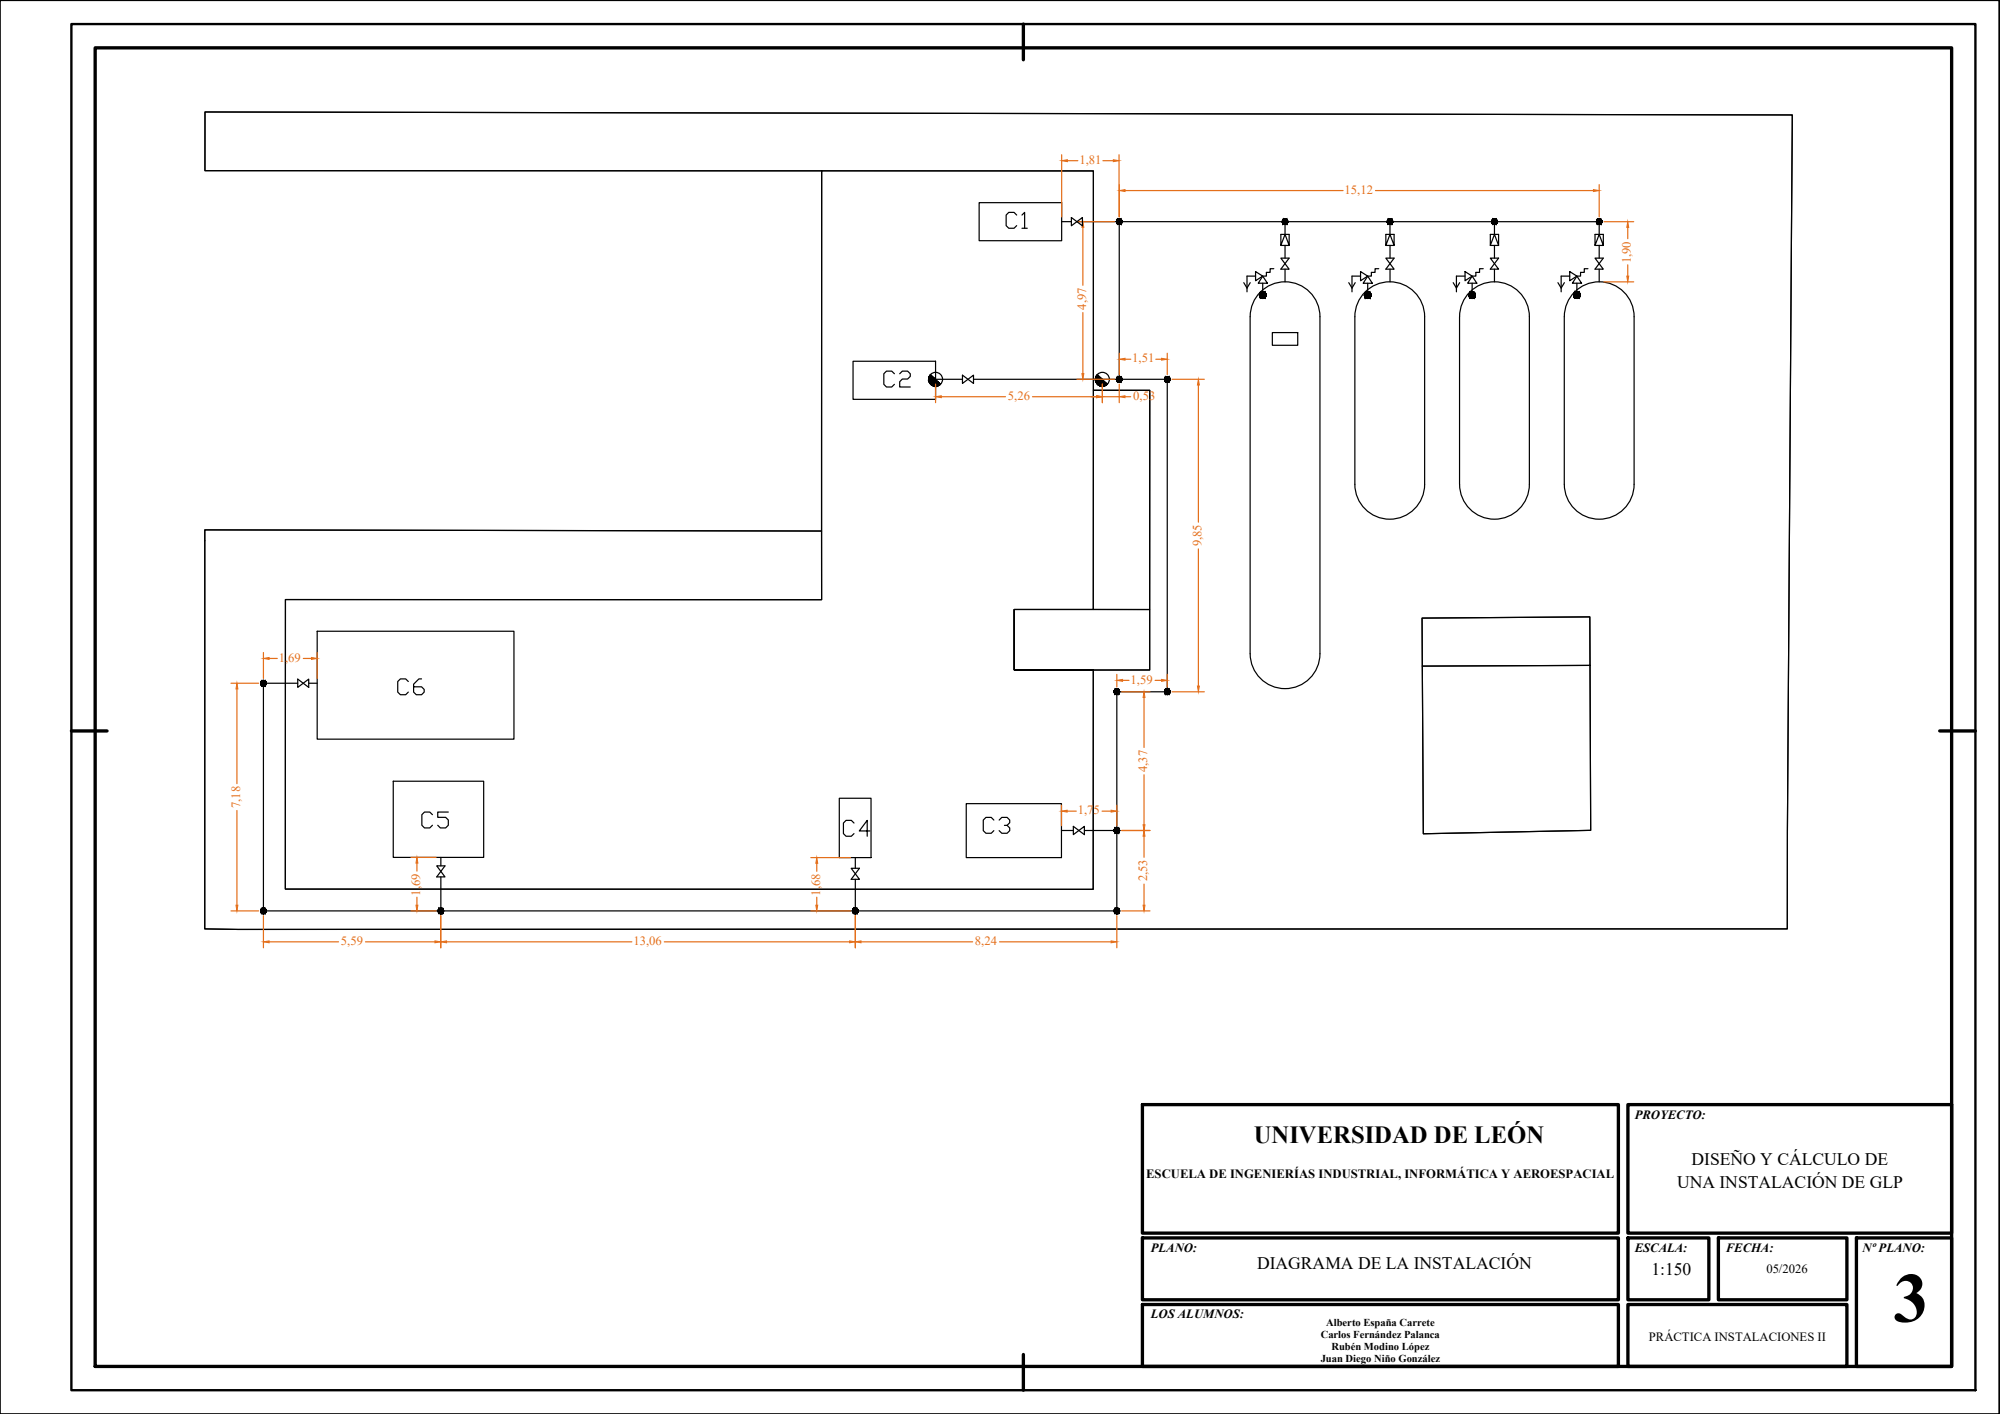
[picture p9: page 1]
LOS ALUMNOS:; ESCALA:; FECHA:; Nº PLANO:

UNIVERSIDAD DE LEÓN

DISEÑO Y CÁLCULO DE
UNA INSTALACIÓN DE GLP

ESCUELA DE INGENIERÍAS INDUSTRIAL, INFORMÁTICA Y AEROESPACIAL

DIAGRAMA DE LA INSTALACIÓN

Alberto España Carrete Carlos Fernández Palanca Rubén Modino López

PRÁCTICA INSTALACIONES II

Juan Diego Niño González

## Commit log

2026-05-01 Initial project setup and LPG tank sizing calculations
    [caudal_vaporizacion.csv, deposito_vaporizador_interno.csv, instalacion_GLP.dwg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]
2026-05-02 LPG tank sizing calculations V2
    [caudal_vaporizacion.csv, instalacion_GLP_escala_deposito.dwg]
2026-05-05 Minor changes
    [instalacion_GLP.dwg, instalacion_GLP_escala_deposito.dwg, plano_instalacion_GLP.dwg]
2026-05-11 Justify GLP plant layout and fire protection per UNE 60250
    [plano_instalacion_GLP.dwg]
2026-05-14 Update project data and next steps
    [DATOS GRUPOS-2026.xlsx]
2026-05-14 Update CAD drawing files
    [Emplazamiento_nave_GLP.dwg, plano_instalacion_GLP.dwg, prueba.dwg]
2026-05-14 Preserve CAD session artifacts
2026-05-17 Add LPG accessories research report with catalogs and pricing
    [plano_instalacion_GLP.dwg]
2026-05-17 Document heating cabinet power sizing for GLP vaporization
    [plano_instalacion_GLP.dwg]
2026-05-20 Update accessory specs to comply with UNE standard
    [plano_instalacion_GLP.dwg]
2026-05-21 Rename LPG pipe segments for sizing
    [Longitudes_Tramos.xlsx, plano_instalacion_GLP.dwg]
2026-05-21 Update base template for industrial LPG project
    [longitudes_Tramos.csv, plano_instalacion_GLP.dwg]
2026-05-21 Sizing calculations and documentation for LPG project
    [longitudes_Tramos.csv, plano_instalacion_GLP.dwg]
2026-05-22 Revise LPG installation sizing parameters
    [plano_instalacion_GLP.dwg]
2026-05-22 refactor: refine LPG sizing calculations and integrate project drawings
    [plano_instalacion_GLP.dwg]
2026-05-22 feat: initial installation budget estimate and enhanced document traceability
2026-05-22 fix(latex): resolve document compilation errors and synchronize template │ versions
2026-05-23 docs: develop specification framework for LPG installation design and calculation report
2026-05-23 refactor: compact GLP sizing notebook and fix project template build
    [plano_instalacion_GLP.dwg]
2026-05-24 docs: reinforce technical traceability between calculations and project specifications
2026-05-24 docs(latex): editorial cleanup — figures, bibliography and formatting
    - Add inline figures with captions and cross-
    references
    - Remove duplicate bibliography and ghost annex index
    - Drop \nocite{*} to list only cited references
    - Migrate tables to tabularx and booktabs style
    - Replace academic group label with professional terminology
    [plano_instalacion_GLP.dwg]
2026-05-24 docs: final document formatting and bibliography update for submission
    [caudal_vaporizacion.csv, deposito_vaporizador_interno.csv, longitudes_Tramos.csv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]
